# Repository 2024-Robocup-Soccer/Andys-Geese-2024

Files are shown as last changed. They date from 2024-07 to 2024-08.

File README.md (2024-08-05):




<h1 align="center" id="title">Robocup Soccer</h1>

<p id="description">A Lightweight Soccer Robot for Robocup Junior. Created by Matteo Cericola, John Qing, Sean Yien and Yuan Yoshimi. </p>

Documentation: https://andys-geese-2024.readthedocs.io/en/latest/

RoboCup is an international robotics tournament held around the world every year. More information can be found here: https://www.robocup.org/. The tournament we participated in this year was RoboCup Junior Lightweight.

<h2>Competition and Awards</h2>

2024 RCJ National Soccer Champion (Toronto)

2024 RCJ Regional Soccer Champion (Montreal)

2024 RCJ Regional Soccer Super Team Champion (Montreal)

<h2>3D Model Link</h2>

[https://a360.co/3x0yv2s](https://a360.co/3x0yv2s)

<h2>Project Pictures:</h2>

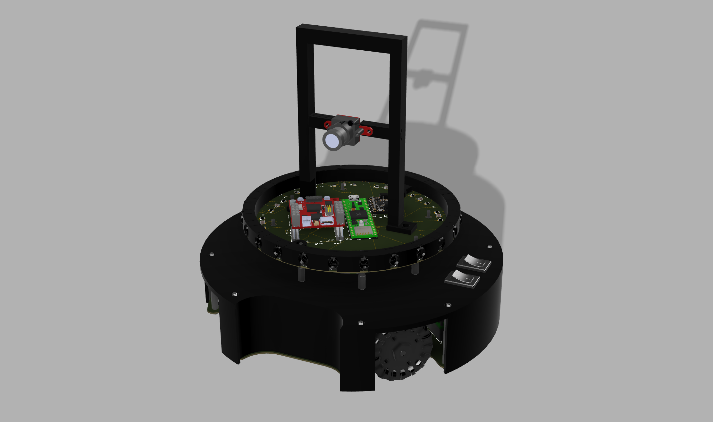
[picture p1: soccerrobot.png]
project-screenshot
 

project-screenshot 

<h2>💻 Built with</h2>

Technologies used in the project:

*   Fusion 360
*   VS Code (PlatformIO)
*   Prusa MK4 3D Printer
*   Teensy 4.1
*   OpenMv Camera
*   Adafruit BNO085 Compass
*   TSSP4038
*   GTF 50mm Omniwheels
*   GA25YN370 12V 1000RPM Motors
*   Pololu G2 High-Power Motor Driver 18v25
*   Photodiodes


CC BY-SA 4.0

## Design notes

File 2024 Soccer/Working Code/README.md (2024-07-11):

## Working Code
Here is where all the code being currently edited goes

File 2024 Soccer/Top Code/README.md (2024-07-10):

## These are the codes that are used in the top teensy.

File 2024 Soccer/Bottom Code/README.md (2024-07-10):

## These are the code for the bottom teensy.

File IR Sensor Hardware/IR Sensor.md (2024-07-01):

# Our IR Sensor
## Materials
- 12 TSSP4038 connected to a RC lowpass filter
- 12 TSSP4038 connected directly to a teensy 4.1

## Code
It uses a Taylor series to determine a function associated with the relationship between the intensity of the ball's signal and its distance from a given point.

## Shroud
After testing, we found that using a conical funnel directed toward the face of the sensors allowed for more reliable intensity values

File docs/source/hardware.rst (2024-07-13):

.. _hardware:

Hardware - Our Designs and Electronics
======================================

This section of the documentation will go over the specifics around our hardware, such as our electronic design process and 3D modelling.

We use Fusion 360 and Fusion 360 Electronics as our CAD software, and like before, associated files are available at our `GitHub <https://github.com/YuanYoshimi/RCJ-Soccer-Robot/>`_.

If you would like to download Fusion 360, the education edition is `free <https://www.autodesk.com/ca-en/products/fusion-360/education>`_. It contains all aspects of the paid license and is available to all students. Our files can be opened with the proper Fusion 360 Electronics and Fusion 360 software.

.. toctree::
    Infrared Sensors <irsensors>
    Color Sensors <colorsensors>
    3D Design <models>
    Design Process <dp>
    PCB Design <pcb>

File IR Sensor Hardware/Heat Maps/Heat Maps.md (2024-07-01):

These diagrams show the sensor output intensity when the ball is placed at any spot around it.

They were made by recording the intensity of each sensor when the ball was placed in seven 14 cm intervals infront of each sensor. The data was collected using the irCollection.ino file and the graph was made using gnuplot.

NOTE: THIS WAS THE OLD SENSOR WITH ONLY TSSP4038s CONNECTED TO A RC LOWPASS FILTER

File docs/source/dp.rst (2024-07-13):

.. _dp:

Design Process
==============

Our robot has undergone many iterations since the first protype design. However, we maintained a similar basic functionality all throughout. We identified the need for robot movement, orientation and ball detection as the required base functionality and therefore the highest priority to complete. As such, the first prototype iteration of the robot to explore these technologies included these three aspects of RCJ Soccer. The image to the right illustrates the prototype iteration of our robot, with the Modern Robotics IR Locator 3601, the Progressive Automations MultiMoto Arduino Shield with 4 H-Bridges2, a CMPS-123 (with BNO055 IC), and an Arduino Mega4 as the processor.

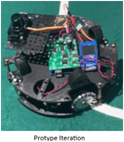
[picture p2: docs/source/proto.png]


The next iteration of the robot, the Regional Competition Iteration, we replaced multiple components and introduced the use of printed circuit boards to facilitate the transfer of data, as well as to provide a solid base and electrical pathways for the power supply. We also introduced the use of a 5V and a 3.3V step-down regulator in order to feed proper voltages to the new Teensy 4.1, BNO085, and ADG732 (referred to internally as the MuxBreakout). The image on the left shows all components mounted on both the top and bottom PCBs.

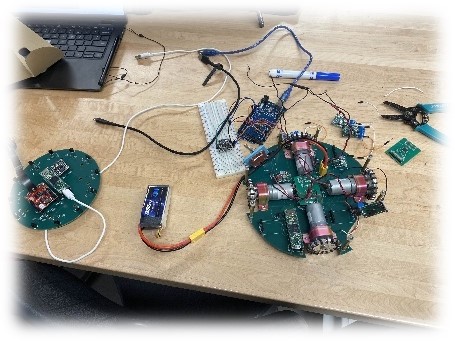
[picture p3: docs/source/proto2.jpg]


We stopped using the IR Locator 360 due to the unreliability as well as the halted production of the component. Instead, we opted for an IR Ring that employed the use of the TSSP4038, an IR receiver produced by Vishay. We also created a line sensor array with a colour sensor photodiode from Advanced Photonix, the 019-141-411-R SMD photodiode. The first iteration of the line sensor array used the OSRAM LS G6SP.02 SMD LED5 (see footnotes for reasons we no longer use this component). An OpenMV RT1062 was also mounted on the IR Ring and connected using extension cables to the mounting position on the handle of the robot.

The final iteration of the robot, the World Competition Iteration, involved all of the previous capabilities, with improvements to several systems and components. The bottom PCB had some fixes for mistakes on previous boards, different components, and filleted edges. Some problems with the MuxBreakout were also fixed, like a misplaced trace that was not caught by the DRC in Fusion 360 Electronics. All the printed circuit boards were switched to black, in order to minimize disruption to the IR sensors from reflected IR signatures.

The IR PCB was heavily modified. The sensor array was changed to 24 sensors, with 12 of them using a low-pass filter to convert the reading to an analog voltage based off distance, then read through the ADC (Analog to Digital Converter) on the Teensy 4.1 mounted on the IR Ring and the other 12 being directly read from the digital pins of the Teensy 4.1 by measuring the length of the pulses. This pulse measurement system will be explained further in the electronics section. The camera’s communication system was also switched over to SPI, to account for the difficulty in opening more than two serial ports on the Teensy 4.1. This will be discussed further in the technical sections.

Our game strategy was primitive in the Prototype Iteration. The only objective was for the robot to move forwards when the ball was directly in front. There was a BNO055 to do some adjustments, in case the robot ever stopped pointing forwards. The robot could not detect lines (see below) and would regularly violate the rules in search of the ball.

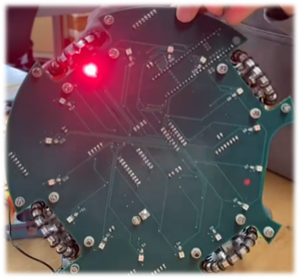
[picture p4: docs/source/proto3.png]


As you can see, the non functioning LEDs resulting in our color sensors being unusable.

The game strategy for the Regional Competition Iteration was slightly more complex, using a better BNO085 to adjust for angle, as well as a camera to aim for the goal. The new motor drivers allowed for more accurate motor speed control. However, some issues with the first LED generation caused the line sensors to malfunction, leading to an inability to control our robot’s movements within boundaries.

Finally, the game strategy for the Worlds Competition Iteration was much more complex. The angle correction featured a PID controller in order to prevent overturning and subsequently overturning again on the correction turn when the robot was wildly rocked out of control. We also identified five variables that we must always account for during the game. These were: ball angle (relative to the robot’s direction), ball distance (relative to the robot), robot direction, robot x (relative to the starting point), robot y (relative to the starting point). With these, we can perform PID again on the values to accurately move behind the ball and direct it to the goal with the help of the mounted camera. The values would work in tandem to the line sensors, which could provide an update to the x and y positions to account for any drift in the accelerometer.

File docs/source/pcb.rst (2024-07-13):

.. _pcb:

PCB Design
==========

Layer Stack
-----------

After doing much research, we decided to opt for a 4 layer PCB since it only requires a marginal increase in PCB production cost.

Our layer stack is illustrated here:
::
    Top -> Signal Layer
    Middle1 -> GND Plane
    Middle2 -> Pwr Plane (highest voltage takes priority, all other voltages are on a signal layer
    Bottom -> Signal Layer

You may notice that we have isolated power from our signal layers. Not only does this make it much easier to route the PCB (the different components who need power can just receive it from a via to the correct layer), it also helps prevent electromagnetic interference. Since pushing a voltage through a trace creates an electromagetic field around the moving electrons, by isolating the power with the signal, we have less chances of interference where the electromagnetic field created in the traces cause a current in the signal traces and renders our signals unreadable.

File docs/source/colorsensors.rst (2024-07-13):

.. _colorsensors:

Color Sensors
================

Principle
---------

The principle behind most color sensors (ours and commercial included) focuses on a basic physics concept known as color theory. As I'm not a real teacher, I am not fully qualified to teach this principle, but I can give a quick breakdown.

White light consists of three (primary) different colors: Red, Green, and Blue. We can make any color by mixing those. The reason we perceive that all objects have colors is because when white light (sunlight) is shone on the objects, their surface reflects a combination of Red, Green and Blue in order for those colors to mix and allow us to perceive a color. The surface in question, depending on their color, will absorb all light that doesn't reflect that color. Therefore, if we look at a green table under a white light, it absorbs all the other colors of light and reflects green light, which allows our eyes to perceive green. You may already know this but if you do not, here is an image that explains it better than me, courtesy of BYJU:

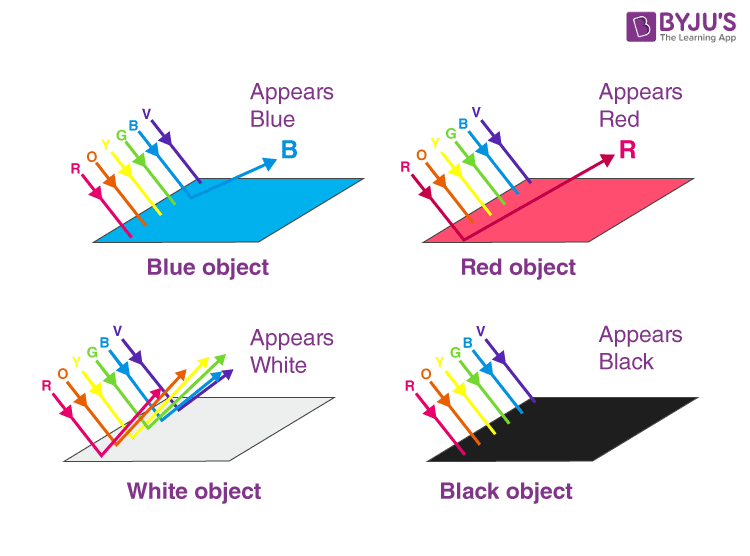
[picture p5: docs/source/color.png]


Thus, if a photodiode, filtered so that it only detects a certain color is pointed at the soccer table and provided with a color of light that will be absorbed by the green field and reflected by the white lines, is placed onto the bottom of the robot, it should in theory push a voltage if it is exposed to the white line.

In our case, the red LED will shine towards the field. If it hits the white line, it would reflect a red light to the photodiode. However if it hits the green field, the red light source does not have a component color of green to reflect. Therefore, the voltage reading should be lower.

This means that the photodiode can just push a voltage that can be read from an MCU.

The photodiode does not need to be connected to power, rather, it can be connected on one end to ground and one end to the analog pin. This is because it can push a voltage without needing a current, given a voltage can exist without current but not vice versa.

Again, arduino works remarkably well for this.

By running a simple analogIn(), the ADC on board can evaluate this analog value for the photodiode, and we can see a clear difference between the line and field.

Execution
---------

As always, principle works very differently from execution.

In this case, we first purchased a photodiode (THT and filtered for 940nm) and tested with a cheap THT (through hole technology) red LED. This actually (surprisingly) gave usable values.

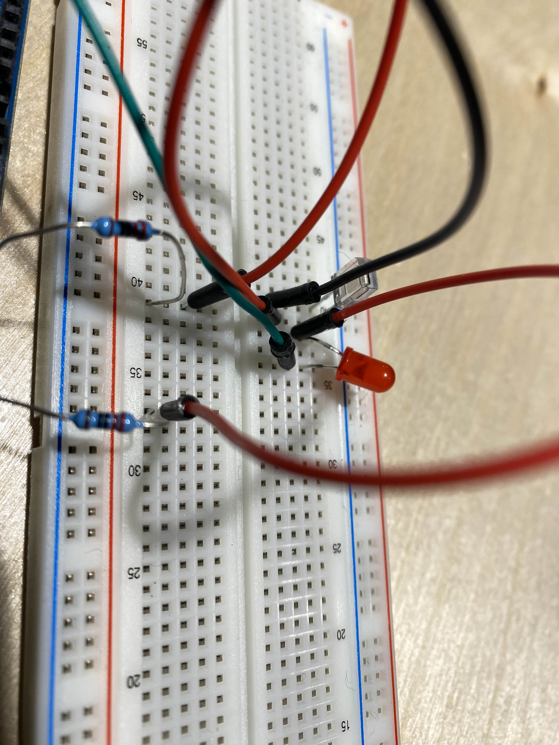
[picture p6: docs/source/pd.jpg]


We then adapted this design onto our bottom PCB.



However, since most MCUs don't have enough analog pins for an array of these, we had to make use of a multiplexer. Given our limited space, we opted for an SMD QFP package (search this up if you don't know what it is) 32 channel multiplexer.

We settled on the ADG732:

`Datasheet <https://www.analog.com/media/en/technical-documentation/data-sheets/adg726_732.pdf>`_

By placing this on a separate PCB and adding pin headers, we can make this modular and easy to replace in case of damage.

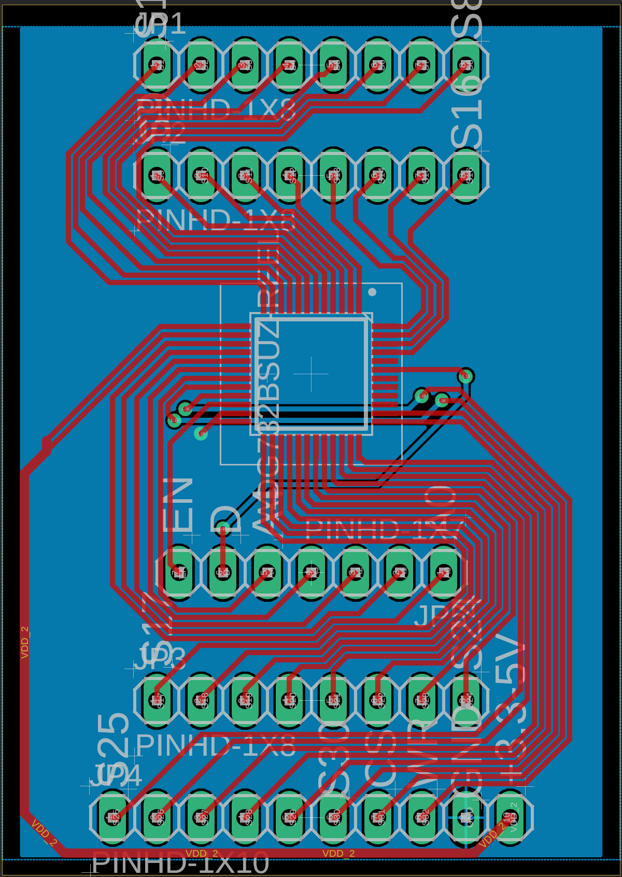
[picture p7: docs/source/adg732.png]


Now, by switching around the ports with code (through values given in the truth table), we can access each individual color sensor on the array.

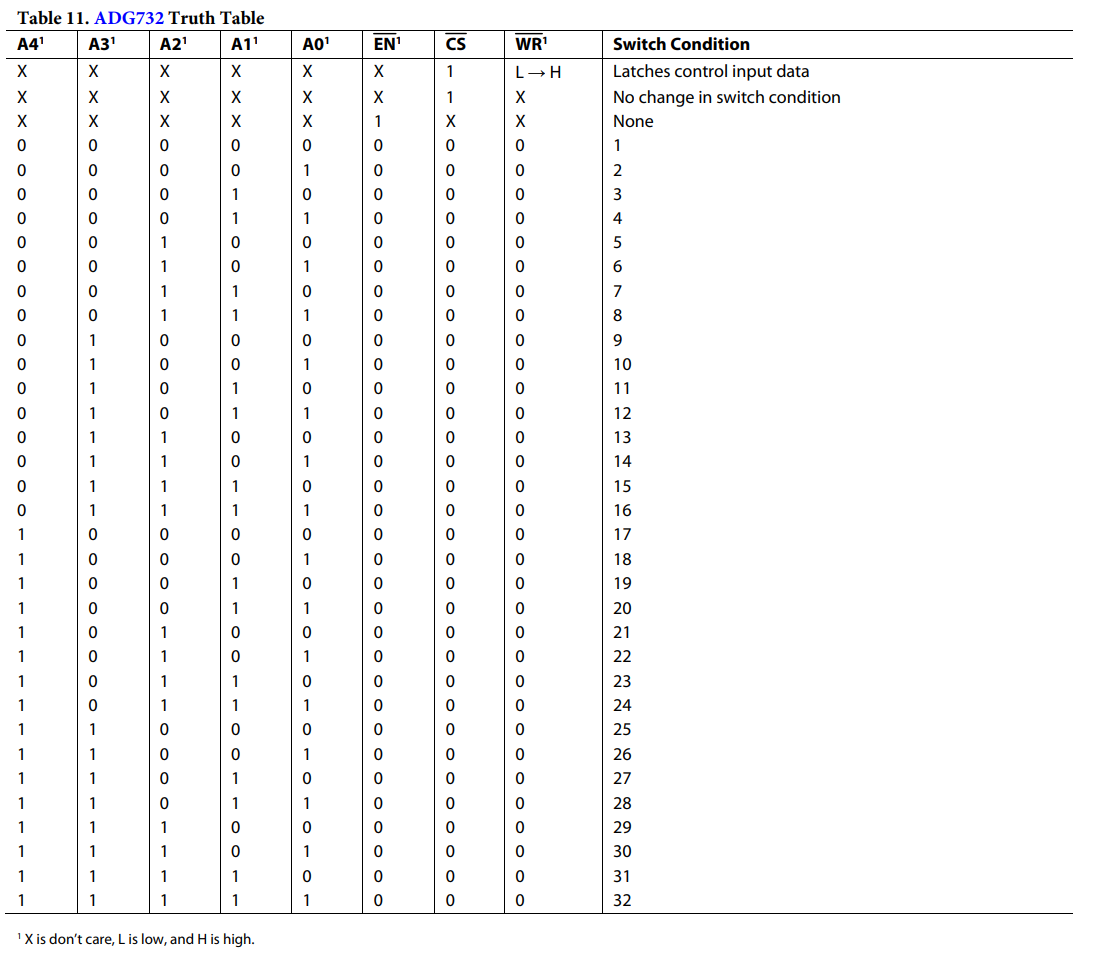
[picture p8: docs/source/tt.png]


The resulting PCB is shown below:

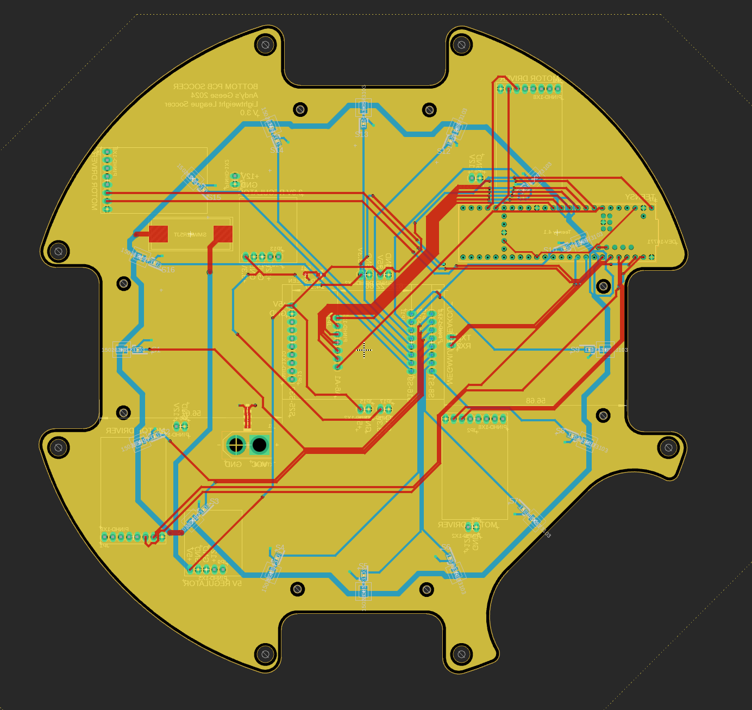
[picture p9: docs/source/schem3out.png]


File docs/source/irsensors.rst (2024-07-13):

.. _irsensors:

Infrared Sensors
================

The Infrared Sensors we used this year corresponded with the popular choices among past `competitions <https://github.com/robocup-junior/awesome-rcj-soccer?tab=readme-ov-file>`_.

We used the TSSP4038, which was a popular choice for IR detectors. We ordered ours from Mouser, but there are many other distributors who sell the TSSP4038.

`Datasheet <https://www.vishay.com/docs/82458/tssp40.pdf>`_

Initially, we had first experimented with the data output. Our oscilloscope indicated that the output was essentially a square wave. We did not understand the intensities at this point in time, so we placed a low-pass filter on it in order to read the square wave value as an analog input.

After playing around with the capacitor and resistor values as well as adding a pull up resistor, we were able to achieve a circuit with reasonable output on a breadboard. In later PCB designs, we used the same circuitry depicted in the schematic excerpt below:

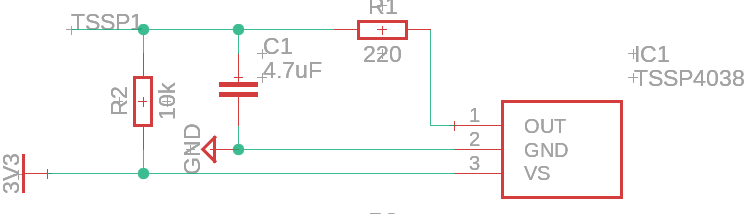
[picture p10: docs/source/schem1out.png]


However, as specified by datasheets and online, the output of the IR ball is quite a bit more complicated than what we saw with this simple circuit.

The ball outputs a stepped waveform of different groups of intensity. That means the ball will pulse at different intensities for a certain amount of times. This is depicted in the diagram below (Mode A since that is what is used in the international competition):

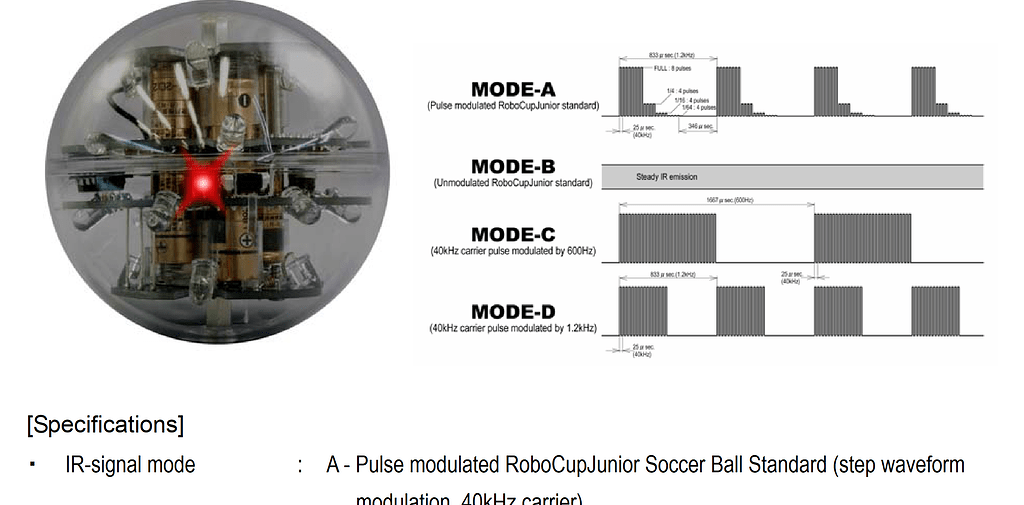
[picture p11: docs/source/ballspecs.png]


Thus, the dropping intensity near the end of the cycle means the further you are from the ball, the less you can see. Naturally, when light intensity drops below a certain threshold, the receivers can no longer distinguish between the ball's light and the ambient light. Therefore, the receiver no longer perceives the lower intensities the further away you move. This means that every time we move out of range of one intensity, the length of the square wave changes. And by sampling for this length, we can determine the distance from the ball, up to a resolution of approximately 5 different distances.

One might now ask, "how would I sample this distance"? Well, for one, pulseIn() on arduino works perfectly fine. What pulseIn() does is measure the length of a digital signal's state that it stays in. So if we connect both the grounds of the arduino (or other arduino avr board) and the receiver (this allows us to work with a common logic signal) and connect the output of the previously mentioned IR receiver, we can just directly pulseIn() to get the length of the pulse.

The code for this is really quite simple, an example is shown (assuming your IR output is connected to pin 1):
::
    //connections:
    //IR Receiver Out -> Digital Pin 1
    //IR Receiver GND -> Board Ground (This syncs their logic base level)
    //IR Receiver VCC -> Read datasheet for appropriate voltage.
    void setup()
    {
        pinMode(1, INPUT);
    }

    void loop()
    {
        int length = pulseIn(1, HIGH, 500); //note that we are reading HIGH, which means that we are looking for the length of the pulse when it is above logic low (logic ground)
    }

Alternatively, the option of using a low pass filter exists. This is because when we move out of an intensity's range, we no longer detect the pulses at that intensity. Therefore, the low pass filter will turn the wave into a lower analog signal, due to the decreased length of the wave.

Both work well, but the low pass filter method is easier if you have a slower MCU, since pulseIn() may not be accurate if your MCU clock speed is too low.

We adapted both low pass and pulseIn() for our PCB design, shown below (also found on our GitHub).

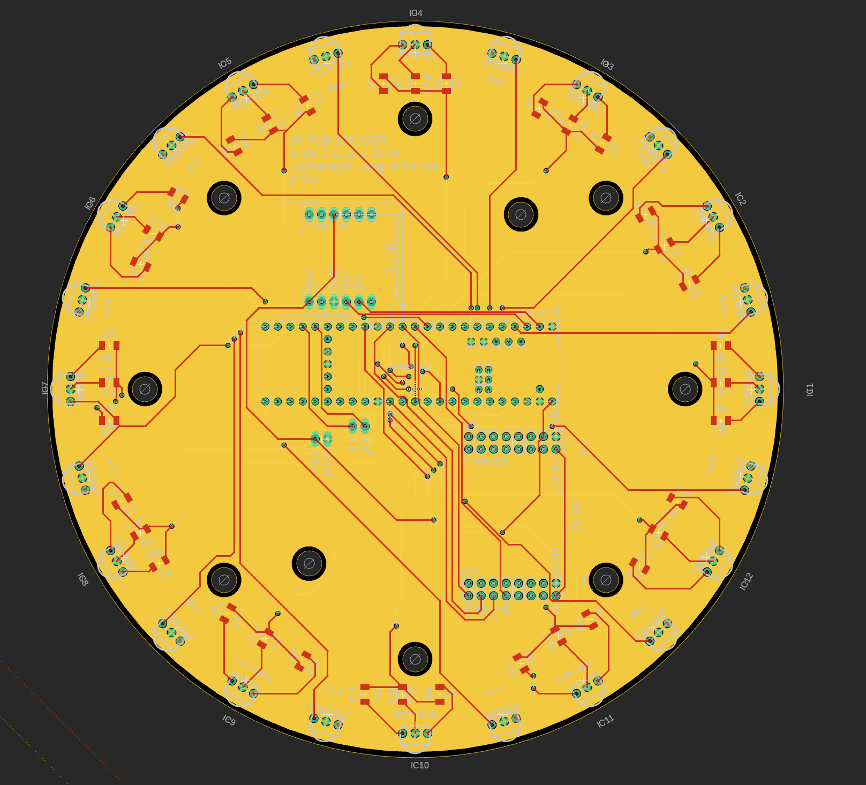
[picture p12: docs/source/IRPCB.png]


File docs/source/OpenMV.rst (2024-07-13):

.. _OpenMV:
OpenMV
======

Camera Detection
----------------

`GitHub <https://github.com/YuanYoshimi/RCJ-Soccer-Robot>`_

Camera detection is accomplished with an onboard library from OpenMV. Originally, we were faced with an issue with incompatibility. The pyb micropython library, which was originally intended for use with the stm32 microprocessor found on the OpenMV H7 was no longer usable with the i.MX RT1062 microprocessor on the OpenMV RT1062. Thus, we had to improvise our communication and detection systems.

**Detection**

The sensor object is still usable with the new microprocessor, so we were able to access the blob class. This class, combined with colorr thresholds, was able to identify the goals given their unique colors.
::

    thresholds = [
       (72, 90, -4, 36, 24, 48),
       (14, 33, -11, 10, -47, -12)
    ]

    blobs = img.find_blobs(thresholds, pixels_threshold=200, area_threshold=200)

This formulates the base of our detection capabilities. However, the camera can still see over the top of the field, so there may be some issues such as detection of blue and yellow shirts and non-game objects. Thus, we limit the detection area to under the halfway point and only identify the largest blob.
::
    if blobs:
        largest = blobs[0]
        for blobsss in blobs:
            if blobsss.area() > largest.area():
                largest = blobsss
    blob = largest
        if blob.cy() > (240/2)+20:
            # These values depend on the blob not being circular - otherwise they will be shaky.
            if blob.elongation() > 0.5:
                img.draw_edges(blob.min_corners(), color=(255, 0, 0))
                img.draw_line(blob.major_axis_line(), color=(0, 255, 0))
                img.draw_line(blob.minor_axis_line(), color=(0, 0, 255))
            # These values are stable all the time.
            img.draw_rectangle(blob.rect())
            img.draw_cross(blob.cx(), blob.cy())

            if blob.cx() < (320/2)-bufferVal:
                print("Left: " + str(int(maptrans(blob.cx(), 0, 320, 0, 250))))
                print(int(maptrans(blob.cx(), 0, 320, 0, 250)))
                pwm.duty_ns(int(maptrans(blob.cx(), 0, 320, 0, 250))*1000)
            elif blob.cx() > (320/2)+bufferVal:
                print("Right: " + str(int(maptrans(blob.cx(), 0, 320, 0, 250))))
                pwm.duty_ns(int(maptrans(blob.cx(), 0, 320, 0, 250))*1000)
            else:
                print("Center: " + str(int(maptrans(blob.cx(), 0, 320, 0, 250))))
                pwm.duty_ns(int(maptrans(blob.cx(), 0, 320, 0, 250))*1000)

            if blob.area() > 8000:

                print("Near")

            # Note - the blob rotation is unique to 0-180 only.
            img.draw_keypoints(
                [(blob.cx(), blob.cy(), int(math.degrees(blob.rotation())))], size=20
            )
        #print(clock.fps())

    else:
        pwm.duty_ns(500000)
    print(pwm.duty_ns())

**Communication**

You will notice that part of the previously created code also includes the communication protocol. Although originally we were planning on using SPI for communication, the difficulty of slaving the OpenMV camera for data transfer so that both SCK pins would not attempt to simultaneously drive the clock signal resulted in us attempting a different approach:
::
    from machine import PWM
    from machine import Pin
    
    p = Pin("P3", Pin.OUT)

    pwm = PWM(p, 1000)

This sets up a PWM object given by the OpenMV library for use with pins on the RT1062. By modifying the duty cycle %, we can send a pulse with a different width. We decided to use this width, measuring in microseconds, to transfer our data.

We began by mapping (see API reference :py:func:`maptrans`) the x pixel value that we get a value from 0-250 that we send in the PWM signal. When there is no goal detected, we will send a PWM signal of 500.
::
    def maptrans(num, inMin, inMax, outMin, outMax):
        return outMin + (float(num - inMin) / float(inMax - inMin) * (outMax - outMin))

Then, we can adjust the width of the pulse (duty cycle %) with `pwm.duty_ns <https://docs.openmv.io/library/machine.PWM.html>`_

This way, when read from the Teensy, we can just use pulseIn().
::
    int val = pulseIn(10, HIGH, 1000);
    if (val>0){
        Serial.println(val);
    }

A value of 1000 for the timeout is required since the width of the pulses are hundreds of microseconds, so we must have 1000 µs as a timeout time in order to catch the entire pwm signal rather than parts of a pwm signal.

The resulting square wave is visible on an oscilloscope. Thus we can be assured that the signal is indeed being produced when degbugging.

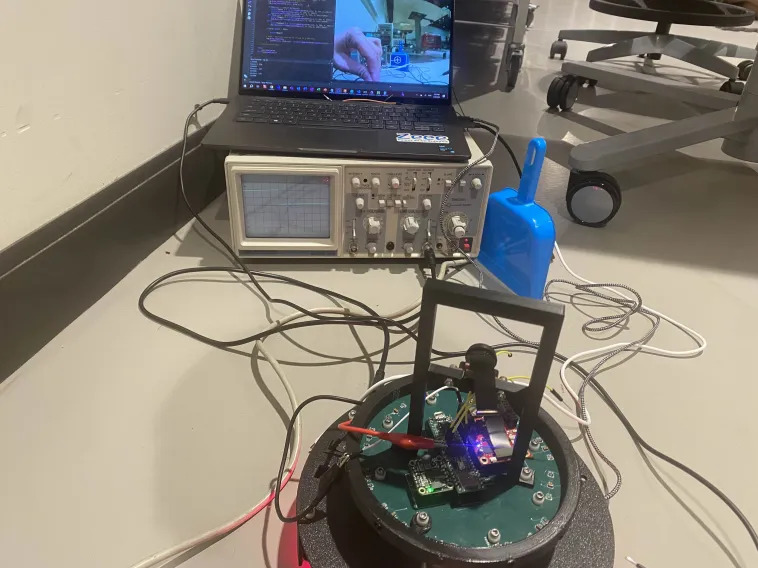
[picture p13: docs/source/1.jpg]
setup picture


API Reference
-------------

.. py:function:: maptrans(num, inMin, inMax, outMin, outMax)

    Translate/map a value from one range to another range.

    :param num: The number to be translated.
    :param inMin: The minimum of the input range.
    :param inMax: The maximum of the input range.
    :param outMin: The minimum of the output range.
    :param outMax: The maximum of the output range.
    :type num: int, float
    :type inMin: int, float
    :type inMax: int, float
    :type outMin: int, float
    :type outMax: int, float
    :return: The value from the original range mapped to the equivalent value of the new range.
    :rtype: int

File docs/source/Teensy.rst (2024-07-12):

.. _Teensy:

Teensy
======

motorControlV3
--------------

.. cpp:class:: motorControlV3::Motor

    Motor class, handles all of our motor controls. Accessed by the bottom file.

    .. cpp:function:: void motorControlV3::Motor::initMotors(void)

        Initializes the pins. Pins are hard-locked to 3, 1, 5, 37 for the direction pins and 2, 0, 4, 36 for the pwm pins for the `Pololu G2 24v21 Motor Drivers <https://www.pololu.com/product/2995>`_.

    .. cpp:function:: void motorControlV3::Motor::setMotor(int motor, int dir, int pwm)

        Sets one motor direction and speed.

            - int motor: Motor number that should have its speed and direction set. Not needed when calling `:cpp:class:motorControlV3::Motor::moveRobot`.
            - int dir: direction value (0 or 1)
            - int pwm: pwm value to send to power motors at a certain speed (0-255)

    .. cpp:function:: int motorControlV3::Motor::movementSineFunction(int motor, float ballAngleDegrees, boolean isCounter, int amplitude)

        Uses a sine function associated with each motor assembly to move in a direction from the according point in the sine wave given the ball direction.

        Returns an integer value for the pwm motor value for the motor given in the parameters.

            - int motor: Motor number that we are calculating the appropriate value for.
            - float ballAngleDegrees: Degrees of ball angle given in the IR code as a floating point number.
            - boolean isCounter: True if motor is backwards, else false.
            - int amplitude: Amplitude of the sine wave, also the distance to the ball that we want to stay away when navigating to the perpendicular.

    .. cpp:function:: void motorControlV3::Motor::moveRobot(int speed1, int speed2, int speed3, int speed4)

        Move robot with the speeds given for motors 1-4.

            - int speed1: Speed of motor 1. (Can be -255 to 255)
            - int speed2: Speed of motor 2. (Can be -255 to 255)
            - int speed3: Speed of motor 3. (Can be -255 to 255)
            - int speed4: Speed of motor 4. (Can be -255 to 255)

colorSensorV2
-------------
.. cpp:class:: colorSensorV2::ColorSensor

    ColorSensor class, handles all the input from our color sensors. There are 16 color sensors: 16 LEDs and 16 940nm photodiodes. All photodiodes output an analog value which is read by the ADC of our bottom Teensy.

    .. cpp:function:: int colorSensorV2::ColorSensor::readSensor(int sensor)

        Read the sensor specified and returns an arbitrary int value for the detected amount of red light that is used in comparisons with other values.

            - int sensor: Takes the sensor pin number. Refer to schematics for sensor numbers.

    .. cpp:function:: void colorSensorV2::ColorSensor::colourSensorInit(void)

        Initializes color sensors. Takes no parameters.

Compass
-------

.. cpp:class:: Compass::Compass

    Compass class, uses Adafruit.h as a dependency for access to the BNO085 compass output.

    .. cpp:function:: void Compass::Compass::init(void)

        Initialize the compass by beginning Serial connection to the BNO085.

            Does not print anything and just opens the connection.

    .. cpp:function:: void Compass::Compass::initPrint(void)

        Initialize the compass by beginning Serial connection to the BNO085.

            Prints a confirmation message and opens the connection.

    .. cpp:function:: void Compass::Compass::resetCheck(void)

            Checks if BNO085 has been reset. Sets the desired output again.

                Does not print a confirmation message and just performs the check and set.

    .. cpp:function:: void Compass::Compass::resetCheckPrint(void)

            Checks if BNO085 has been reset. Sets the desired output again.

                Prints a confirmation message and performs the check and set.

    .. cpp:function:: float Compass::Compass::getBotAngle(void)

            Gets the current bot angle based off the BNO085

                Returns a floating point value of the angle scale value from -1.00 to 1.00 where 0 is the direction it initializes in.

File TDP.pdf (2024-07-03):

Team Design Paper: Andy’s Geese

John Qing, Matteo Cericola, Yuan Yoshimi, Sean Yien, Josh Wang (retired) Dr. Benjamin Lawrence, Ms. Meera Balendran St. Andrew’s College
15800 Yonge Street, Aurora, ON, CA

Abstract
This report serves as the documentation and description for team Andy’s Geese in preparation for RoboCup Junior 2024. In this paper, we discuss aspects of our team and the composition of our robots, as well as details of learning. We will begin by describing our team, then identifying the composition of the technology in our robot, and finally discussing some future steps as well as what we had learned.

Introduction
Team Background
Team Photo

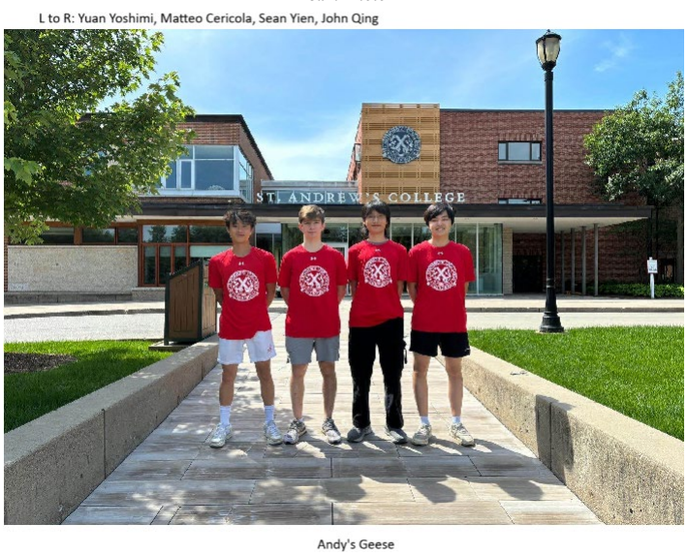
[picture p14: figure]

Team Foundation
Andy’s Geese was first formed in February 2024 in preparation for RoboCup 2024. We were planning on competing in our regional tournaments in April of 2024 and possibly in the world tournament in July of 2024. Although our team formed very
recently, our founding members were part of the DYMJ-Alpha (picture to the right) who competed in Bordeaux in 2023. Other members also brought a wealth of experience, with one hailing from the Canadian Rescue Line team that participated in the Bordeaux competition, and the other with a wealth of experience in embedded systems programming and a mastery in C++.

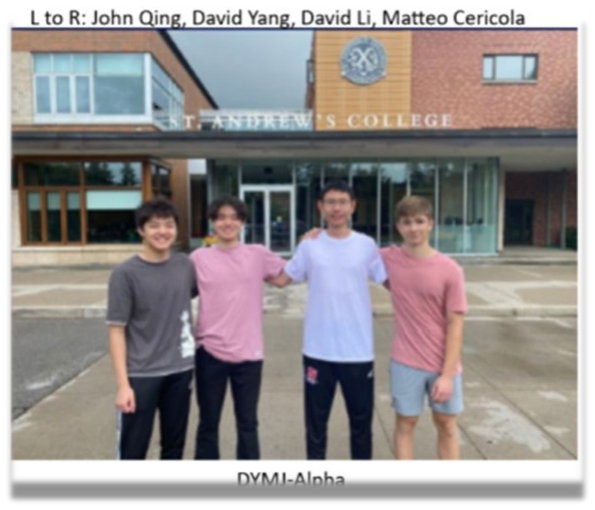
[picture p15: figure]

Team Composition
Our team consists of four people, with one former member who retired from active participation in RoboCup Junior.
Active Members:
John Qing – Engineer, Programmer, Electrical Design, Design Paper Writer, Data Analysis
Matteo Cericola – Programmer, Engineer, Data Analysis
Yuan Yoshimi – Engineer, Programmer, Data Analysis, 3D Designer, Mechanical Deisnger
Sean Yien – Electrical Design, Engineer, Poster Design
Former Members:
Josh Wang – Programmer, Poster Design

Team Accomplishments and Qualification Our team achieved both first place in the regular competition as well as the Superteam competition in the RoboCup Junior Regional Tournament in Montreal, Quebec. We faced many competent teams from Eastern Canada. Less than a week later, our team also achieved first place in the RoboCup Junior National Tournament in Aurora, Ontario (pictured to the left).
After receiving word of our qualification to the RCJ World Championships in Eindhoven, we began work on our final iteration of our robot we intend to bring to the Netherlands.

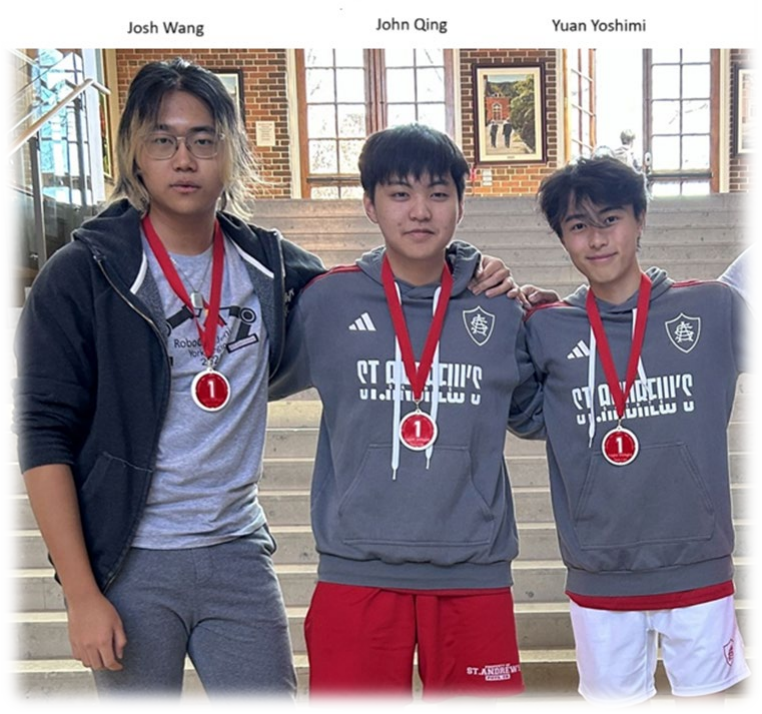
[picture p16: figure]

Robot Development
Design Overview
Our robot has undergone many iterations since the first protype design. However, we maintained a similar basic functionality all throughout. We identified the
need for robot movement, orientation and ball detection as the required base
functionality and therefore the highest priority to complete. As such, the
first prototype iteration of the robot to explore these technologies included these three aspects of RCJ Soccer. The image to the right illustrates the prototype iteration of our robot, with the Modern Robotics IR Locator 360¹ ,
the Progressive Automations MultiMoto Arduino Shield with 4 H-Bridges² ,

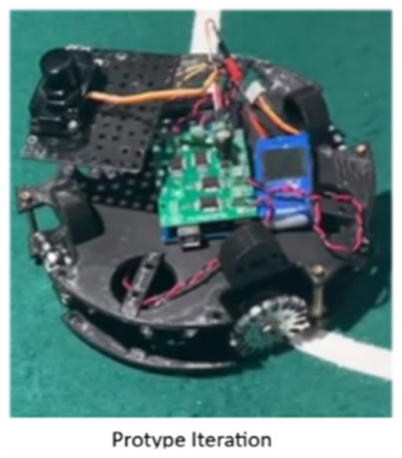
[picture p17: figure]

a CMPS-12³ (with BNO055 IC), and an Arduino Mega⁴ as the processor (see footnotes for reasons we no longer use these).
The next iteration of the robot, the Regional Competition Iteration, we replaced multiple components and introduced the use of printed circuit boards to facilitate the transfer of data, as well as to provide a solid base and electrical pathways for the power supply. We also introduced the use of a 5V and a 3.3V step-down regulator in order to feed proper voltages to the new Teensy 4.1, BNO085, and ADG732 (referred to internally as the MuxBreakout). The image on the left shows all components mounted on both the top and bottom PCBs.

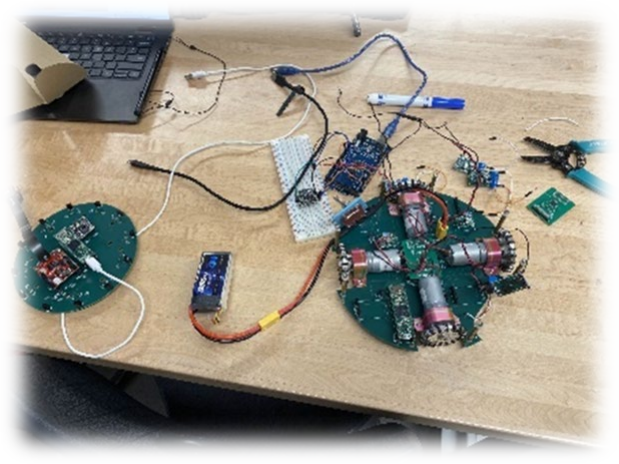
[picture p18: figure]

We stopped using the IR Locator 360 due to the unreliability as well as the halted production of the component. Instead, we opted for an IR
Ring that employed the use of the TSSP4038, an IR
receiver produced by Vishay. We also created a line sensor
array with a colour sensor photodiode from Advanced Photonix, the 019-141-411-R SMD photodiode. The first iteration of the line sensor array used the OSRAM LS G6SP.02 SMD LED⁵ (see footnotes for reasons we no
longer use this component). An OpenMV RT1062 was
also mounted on the IR Ring and connected using

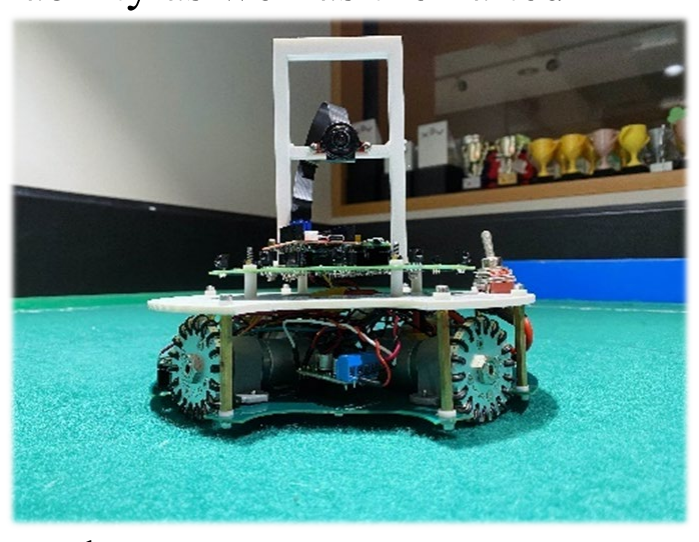
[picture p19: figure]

extension cables to the mounting position on the handle of the robot.
The final iteration of the robot, the World Competition Iteration, involved all of the previous capabilities, with improvements to several systems and components. The bottom PCB had some fixes for mistakes on previous boards, different components, and filleted

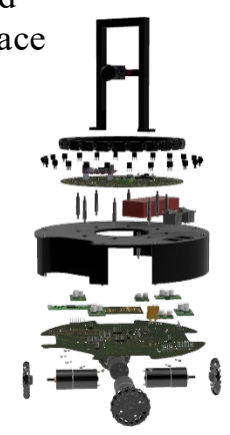
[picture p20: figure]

edges. Some problems with the MuxBreakout were also fixed, like a misplaced trace
that was not caught by the DRC in Fusion 360 Electronics. All the printed circuit
boards were switched to black, in order to minimize disruption to the IR sensors from reflected IR signatures.
The IR PCB was heavily modified. The sensor array was changed to 24 sensors, with 12 of them using a low-pass filter to convert the reading to an analog voltage based off distance, then read through the ADC (Analog to Digital Converter) on the Teensy 4.1 mounted on the IR Ring and the other 12 being
directly read from the digital pins of the Teensy 4.1 by measuring the length of
the pulses. This pulse measurement system will be explained further in the
electronics section. The camera’s communication system was also switched over to SPI, to account for the difficulty in opening more than two serial ports on the Teensy 4.1. This will be discussed further in the technical sections.

Our game strategy was primitive in the Prototype Iteration. The only objective was for the robot to move forwards when the ball was directly in front. There was a BNO055 to do some adjustments, in case the robot ever stopped pointing forwards. The robot could not detect lines and would regularly violate the rules in search of the ball.
The game strategy for the Regional Competition Iteration was
slightly more complex, using a better BNO085 to adjust for angle, as well
as a camera to aim for the goal. The new motor drivers allowed for more accurate motor speed control. However, some issues with the first LED
generation caused the line sensors to malfunction, leading to an inability to
control our robot’s movements within boundaries.

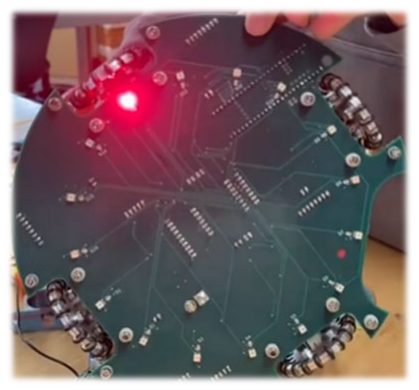
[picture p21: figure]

Finally, the game strategy for the Worlds Competition Iteration was much more complex. The angle correction featured a PID controller in order to prevent overturning and subsequently overturning again on the correction turn when the robot was wildly rocked out of control. We also identified five variables that we must always account for during the game. These were: ball angle (relative to the robot’s direction), ball distance (relative to the robot), robot direction, robot x (relative to the starting point), robot y (relative to the starting point). With these, we can perform PID again on the values to accurately move behind the ball and direct it to the goal with the help of the mounted camera. The values would work in tandem to the line sensors, which could provide an update to the x and y positions to account for any drift in the accelerometer.

Design Specifics
In this section, the details relating to the choices for the mechanical design, as well as trials and failures are documented. Our GitHub repository⁶ (linked in the footnotes) contains all the designs, for public use and for all future teams.
Mechanical Design
The mechanical aspect of the robot was designed with fusion 360 allowing us to model our robot. The 3D printed pieces consist of a main
cover/chassis, handle, motor mount, IR shroud and the motor
standoffs.
Different mechanical parts of the robot experience varying amounts and types of stress, as well as varying material requirements. We have experimented with different types of filament for the 3D prints such as PLA, PETG and a carbon fiber filament. Initially we planned on using the carbon
fiber filament as it has a exceptional strength and
performance, but we found out that the prints were poorly

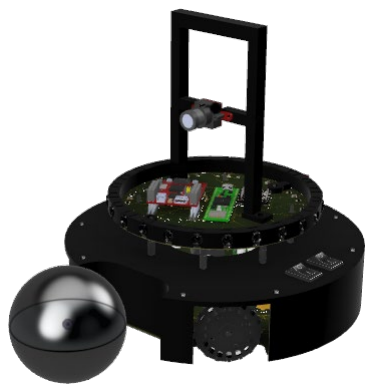
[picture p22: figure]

done and some were unusable. After testing, all our 3d printed pieces are using the PLA filament because of its reliability and the printer working well with it.

Electrical Design
The diagram picture below depicts all the data transferred by all the components and labelled by the communications protocol, as well as the flow of power from the battery. All electrical designs were done on Fusion 360 Electronics, since it provides good integration for the final 3D model.

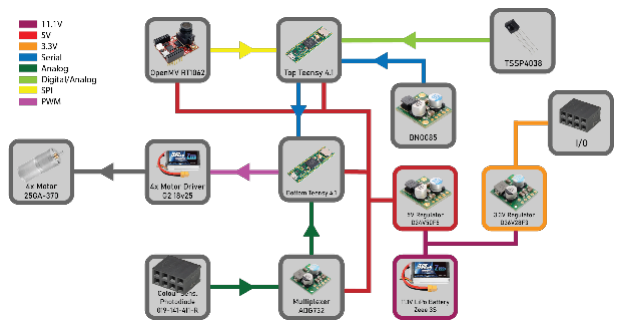
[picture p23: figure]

The schematic for the bottom PCB is shown below. Since we did not go through the trouble of creating custom fusion libraries for the components that we created, like the MuxBreakout board, we ended up just using header pins and accurately measuring the I/O pins of all our own components and the ones we bought commercially.

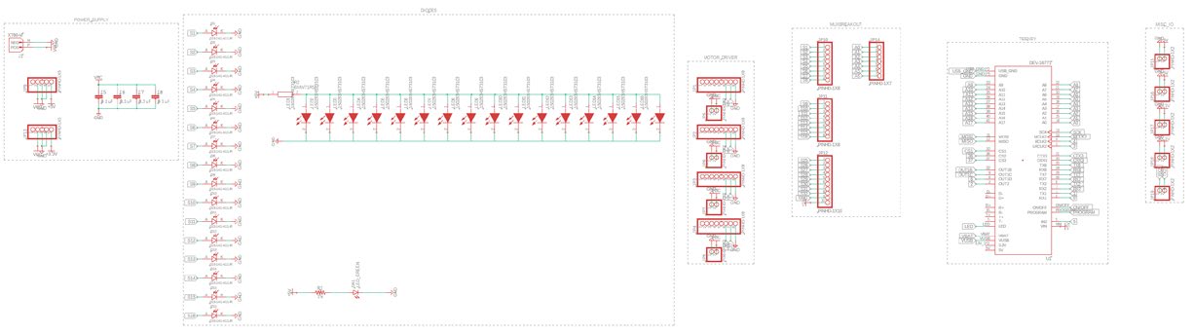
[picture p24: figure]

The layer stack for all of our PCBs is shown to the left. We opted for a 4-layer PCB since it had the same production costs as the 2 layer PCB, with the added benefit of a ground plane and a 12V plane, following PCB design conventions. The layer stack we opted for was signal-ground-12v-signal. This allowed for easy access to the ground planes with vias as well as easy access to the 12V source without needing to run them as traces in the signal plane, thereby reducing EM interference between traces.
In the following image, the schematic and the PCB design for the IR Ring is shown. The ANALOG_IC group contains the low-pass filtered IR receivers. The circuit contains a low pass filter (resistor and capacitor) as well as a 10k pull-up resistor.

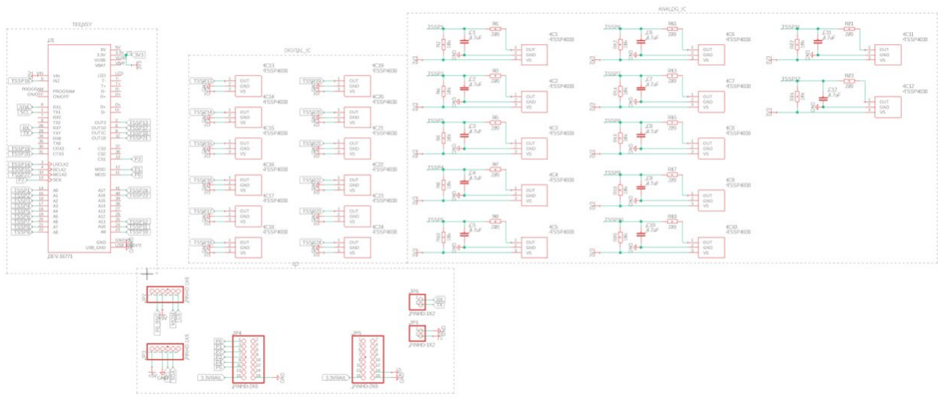
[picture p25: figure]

During testing, we discovered that by limiting the field of view with a shroud, we could more effectively isolate the direction of the incoming IR signature. In the following heatmaps, a shroud was applied to one and not in the other. The directional readings were much better after the shroud was applied. Therefore, with this setup, we can accurately determine the direction of the ball down to approximately 7.5-15 degrees and potentially even more accurate as we get closer.


The principle behind the low-pass filters and measuring the length of the pulses lies behind the trapezoid-wave with steps of intensity of the IR LEDs. As seen in the image below (taken from the RCJ forums)⁷ Mode A, which contains the trapezoid-wave is used. By capturing where signal strength drops off, we can assign that specific length of the square wave to a predetermined location. This can then be read using pulseIn() or a timer-checker loop and a rough distance can be caalculated. In our experience, however, there does not exist enough steps of the wave for certainty in terms of distance, and a low-pass filter to normalize the signal provides better long-distance detection. We decided to use both in order to achieve the maximum resolution at all distances.


Communication is achieved with both SPI and UART. Due to an issue on the Teensy 4.1 where opening more than two Serial ports would interfere with the operation of the
robot, we decided to use SPI for certain aspects of the Robot. UART at the maximum
speed of 20,000,000 Baud can operate at the equivalent data transfer rate of 20 mhz.

This is sufficiently fast for us to transfer instructions for our motors from our top Teensy and receive information from the bottom Teensy to compute.
The MuxBreakout, the custom designed component with the ADG732 multiplexer IC includes a mechanism to keep it permanently on. The IC contains WR (Write),
EN (Enable) and CS (Chip Select) pins. These are all to be set to logic low
according to the truth table from the datasheet provided by the manufacturer
while the IC is operating. Therefore, in our component, we connected all of
them to the same pin that is to be set to logic low. While these traces cannot be
seen in the PCB pictured to the right, they consist of three simple traces
designed to keep this IC on at all times, given that we do not need the extra functionality.
We custom mounted most of the SMT components on our PCBs. To do this, we acquired a T962A reflow oven for amateur use. By ordering stencils from
the factory, we could use a blank RFID card from the RFID kit
provided in Arduino kits and squeegee the solder paste. Since
the solder paste was Lead based and was composed of a mixture of 63% Tin and 37% Lead, we worked in our school’s advanced chemistry lab, where we had access to fume hoods for proper
fume control when using the oven and large quantities of 99.9%
IPA (isopropanol alcohol), the manufacturer prescribed method


of cleaning solder paste from stencils. We placed all components with tweezers and by hand. In order to conform to MSL (Moisture Sensitivity Level)
requirements, we baked all components which were exposed to room
humidity in accordance with the temperature and time described in J-STD-
033. Since we were working with MSL 3 components, we baked all of our components at 125℃ for 9 hours. Since the thickness was below 1.4mm. We used an oven with precise temperature control and watch glasses to contain
the components to be baked.
Software
Behind our robot's program is the consistent development of five values: robot angle, robot x, robot y, ball angle, and ball distance. These values allow the bot to understand the field and determine the best holistic action. In previous years, we had made concrete decisions based on one data collection method. An example would be when our robot detected it was above a line; it would automatically move inward to avoid moving out of bounds. Instead, this year, we have made an algorithm that simply understands it is on the line and restricts movement accordingly. To calculate these values, we are using the Adafruit BNO085 to calculate the robot angle, x, and y, and the IR sensor to find the ball angle and distance from our robot.
These five values are then sent from our top microcontroller to the bottom microcontroller using UART in a six-cycle process. First, 255 is sent to mark the beginning of the cycle, followed by five bytes, each representing each value mapped to a value between 0 and
250. Once received, these values are remapped to their original values to be used to determine the robot’s next move, which is determined by a priority list. As to move, our robot needs to understand how it is oriented, our robot adjusts rotation before anything. After this, it takes into consideration the line and restricts movement past it when it is detected. Then the robot moves behind the ball, and only when it is aligned correctly it moves forward to try and score. This priority list generates a desired angle, x, and y position.
From that, three PID controllers, one for calculating y movement, x movement, and rotation, are fed this desired positioning. These controllers find the displacement required to get to the desired position, the derivative of displacement, and the integral of displacement. The output of these functions are associated motor values that add to make up the total motor value. Each TSSP4038 is associated with a Taylor series function to find the direction and distance of the IR ball. This association is created by measuring the output intensity of each sensor at one-cm increments for two meters. These values are then graphed, and the corresponding Taylor series function is created to fit the curve. Initially, we used an inverse square fit, but as the inverse square law does not fully explain the output, since the silicone also plays a significant role in the shape of the curve, an nth-degree polynomial generated from the Taylor series considers these other factors.
Reflection
We also explored other aspects of improvement for our robot, namely
with the TSSP4P38. This sensor was a derivative of the TSSP4038, but with an AGC that would try and suppress the IR signature. Once it was suppressed, the return of the sensor was the time it takes to suppress the signal as a pwm signal. However, the engineers at Vishay pointed out that the suppression time was
approximately 130ms in some cases, which is just too slow for a fast-paced
soccer game.
We also noted the importance of being able to detect if we are directly in front of the ball, and noted that in a future design, we can open up a hole in the front kicking section of the robot and allow an IR receiver to check if the ball is in the right position.
Finally, we entertained the possibility of a kicker and a dribbler mechanism. While both in theory would be easy to add on even with less than two weeks until the competition since they can be externally attached modules with wires running to them, we decided against implementing them. This is because of the efficiency of kinetic energy transfer when hitting the ball, and the other two would make little difference unless we are working with special methods of hiding and lobbing the ball. Given our time constraints, we disregarded these and focused on our existing parts and getting them ready for the competition.
One very important lesson we learned was the importance of starting early. Since we started about four to five months before the Eindhoven competition, we were faced with many issues such as procuring motors. Most motors that are commonly used in the robocop competitions like Maxon and Faulhaber motors have a lead time of up to a few months. This would massively surpass our timeframe. Therefore, we opted for fast motors from amazon that are low quality but large in quantity. We could speedily replace all of our motors upon failure. But this does not at all mean that starting early would not be hugely beneficial for our robot quality.
Additionally, after conferring with other teams, we concluded that RoboCup innovation is being stifled by the lack of a better trapezoid waveform from the ball. As seconded by the engineers at Vishay, “you probably do not have enough steps and your timing is too short”.⁸ Therefore, more varying intensities could be beneficial, as shown in the diagram below provided in the email from the engineers at Vishay. We could read a pseudo-analog value from our sensors by measuring the width of the pulse as a result, increasing our resolution.


Footnotes and References
1 https://modernroboticsinc.com/product/ir-locator-360/ – No longer produced
2 https://www.progressiveautomations.ca/products/lc-82 – No longer used due to low amperage tolerance and tendency to short circuit from minor mis-operation
3 https://ca.robotshop.com/products/tilt-compensated-magnetic-compass-cmps12 – No longer used in favor of BNO085
4 https://store.arduino.cc/products/arduino-mega-2560-rev3 – No longer used in favor of Teensy 4.1’s Arm Cortex M7 core.
5 https://www.mouser.ca/ProductDetail/ams-OSRAM/LS-G6SP.02-6D5E-67-G3R3-140-R18-Z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 (https://www.mouser.ca/ProductDetail/ams-OSRAM/LS-G6SP.02-6D5E-67-G3R3-140-R18-Z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) – No longer used due to SMD mounting difficulties as well as common short circuits due to the pad positioning
6 GitHub repository: https://github.com/YuanYoshimi/RCJ-Soccer-Robot
7 https://junior.forum.robocup.org/t/ir-ball-modulation-change-proposal/3672

8
Dr. Sebastian Schaefer, Application Engineer, IR-Receiver & IRDA


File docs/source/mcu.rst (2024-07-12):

.. _mcu:
MCUs -  All About Our Code
==========================
This section of the documentation will go over everything code related. An explanation of all the communication protocols, as well as the API references for our custom libraries. Again, you may find the associated code at our `GitHub <https://github.com/YuanYoshimi/RCJ-Soccer-Robot>`_ in the appropriate namespaces.

.. toctree::
   Teensy
   OpenMV

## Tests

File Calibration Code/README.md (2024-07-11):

## Calibration Code
Code within this folder is used to get sample data from which the actual code compares with the data it collects to work

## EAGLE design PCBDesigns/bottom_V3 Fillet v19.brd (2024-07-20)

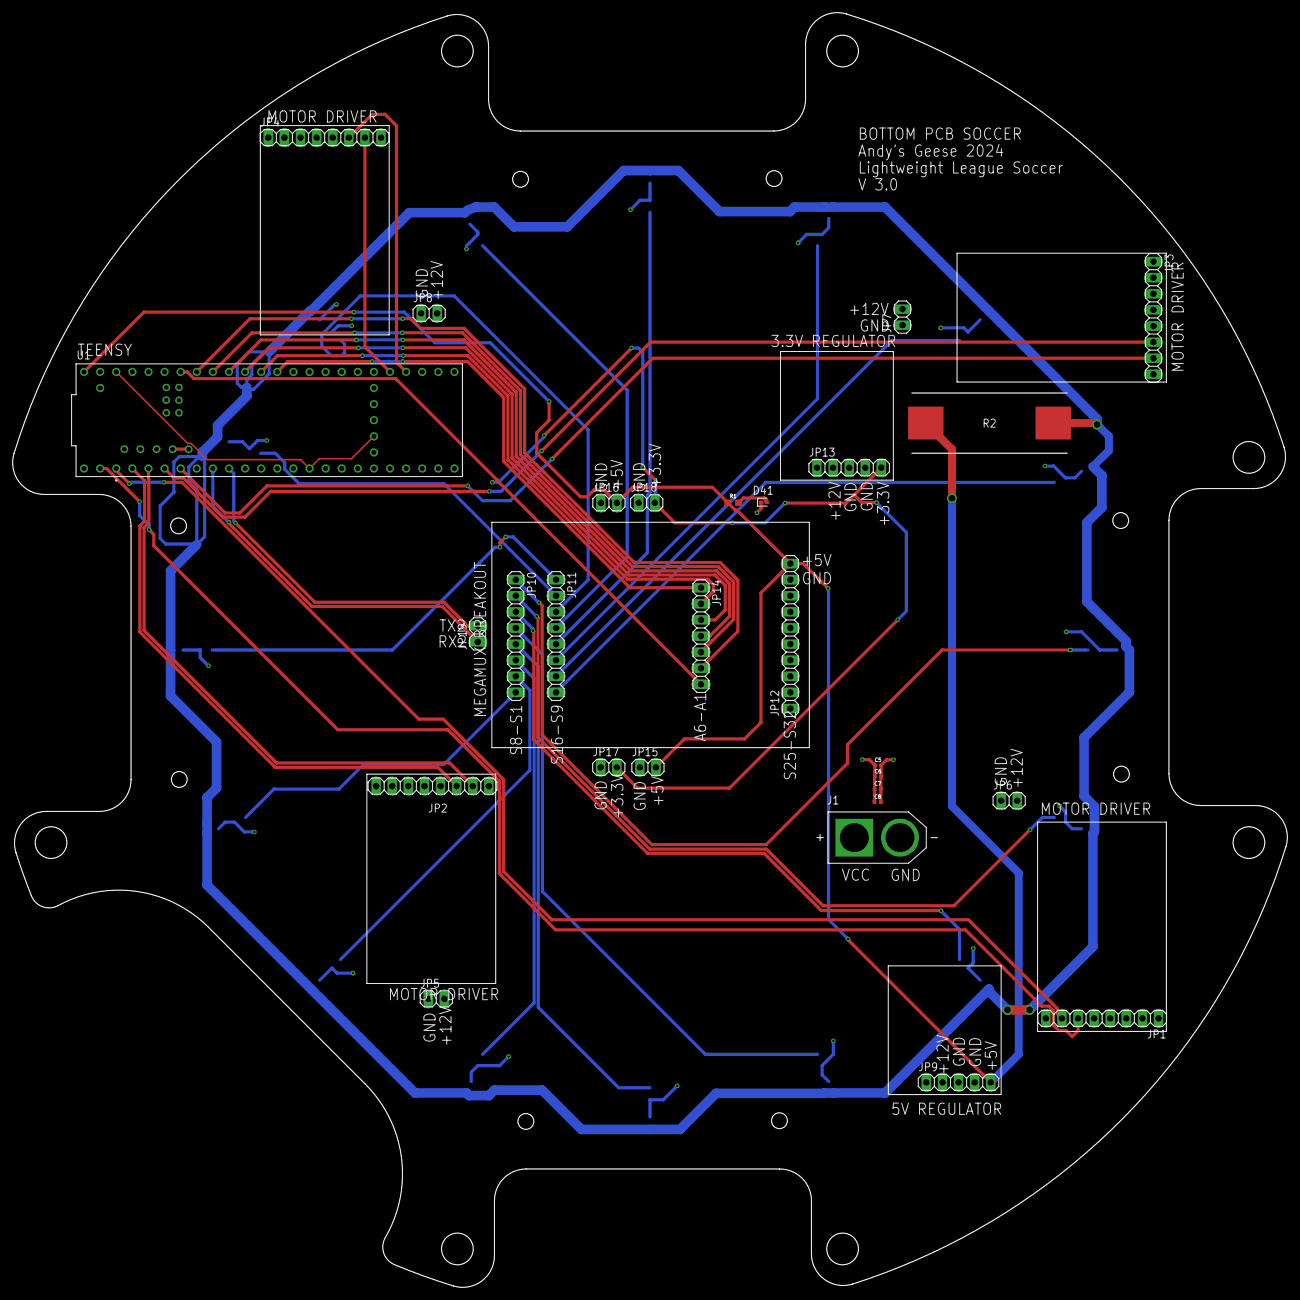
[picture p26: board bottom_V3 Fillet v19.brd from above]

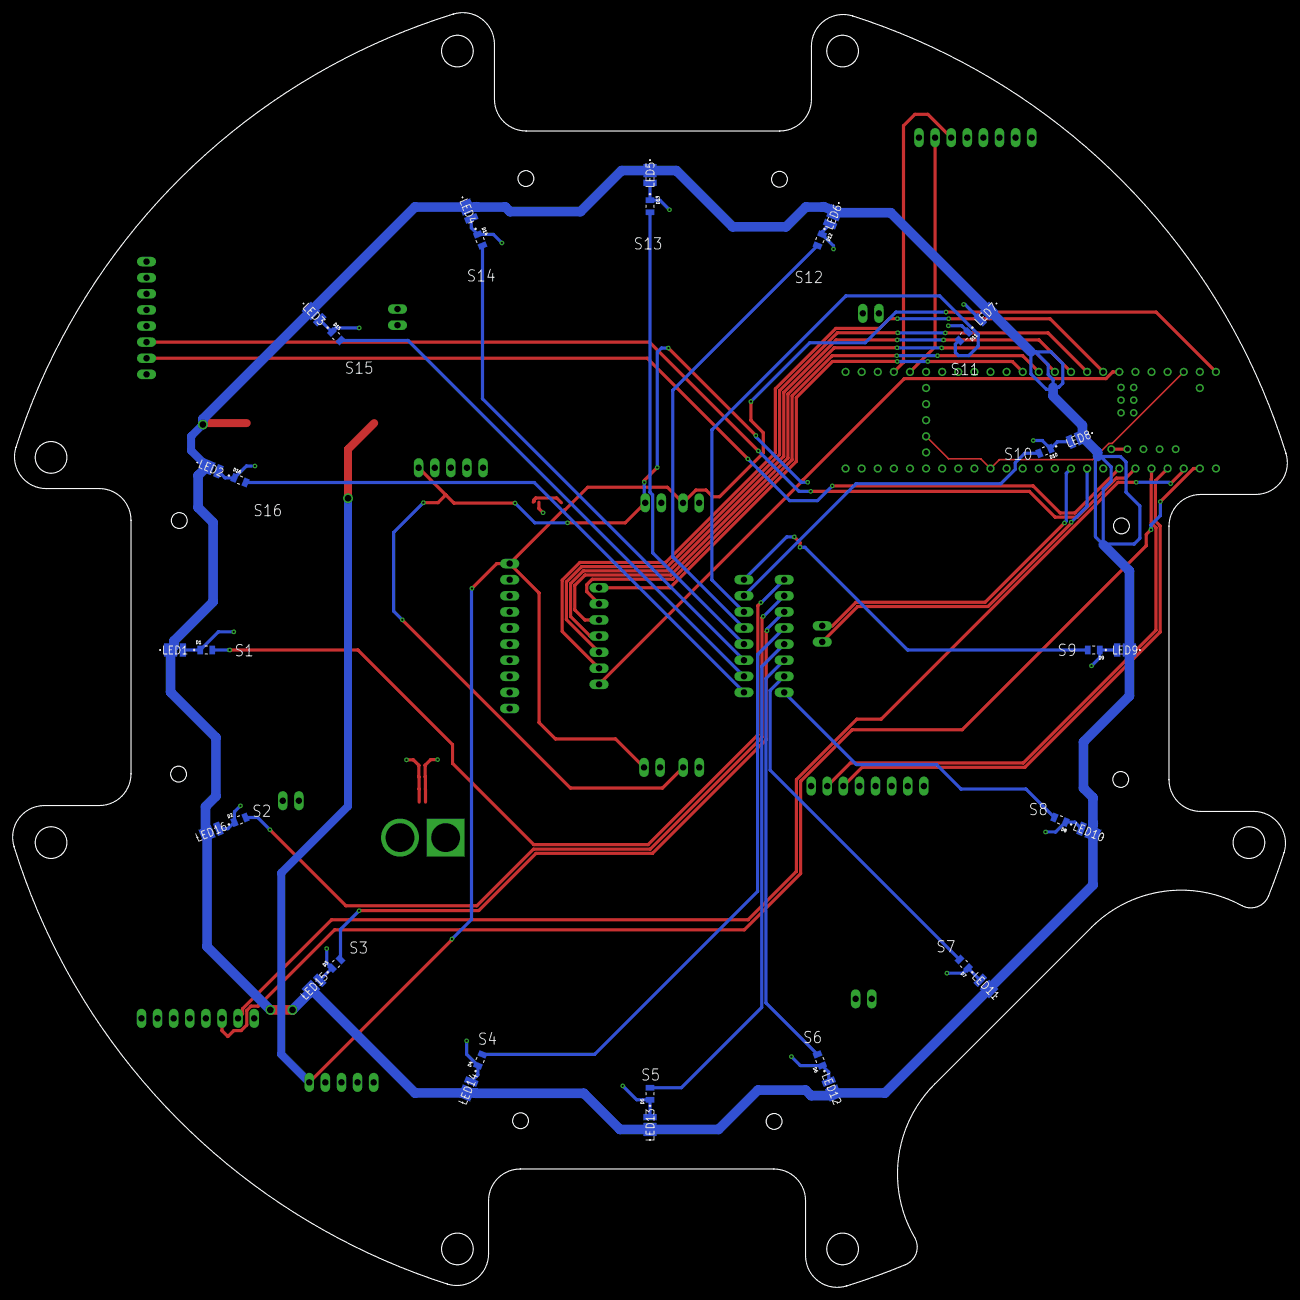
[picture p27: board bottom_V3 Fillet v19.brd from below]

Board: 4 copper layers, 201.1 x 201.1 mm, 60 parts (32 on the bottom side), 41 nets.

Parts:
C5, C6, C7, C8: 0.1uF; 0402-TIGHT
D1, D2, D3, D4, D5, D6, D7, D8, D9, D10, D11, D12, D13, D14, D15, D16: 019-141-411-R; DIOC2012X80N
D41: LED_GREEN; LEDC1005X25N_FLAT-G
J1: XT60-M; AMASS_XT60-M
JP1, JP2, JP3, JP4, JP10, JP11: PINHD-1X8; 1X08
JP5, JP6, JP7, JP8, JP15, JP16, JP17, JP18, JP19: PINHD-1X2; 1X02
JP9, JP13: PINHD-1X5; 1X05
JP12: PINHD-1X10; 1X10
JP14: PINHD-1X7; 1X07
LED1, LED2, LED3, LED4, LED5, LED6, LED7, LED8, LED9, LED10, LED11, LED12, LED13, LED14, LED15, LED16: 150283HS73103
R1: 1k; 0603
R2: SMW71R5JT; RESM24595X990N
U1: DEV-16771; MODULE_DEV-16771

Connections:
0: JP1.6, U1.0
1: JP1.7, U1.1
2: JP2.6, U1.2
3: JP2.7, U1.3
3.3V: U1.3.3V_1, U1.3.3V_2, U1.3.3V_3
4: JP3.6, U1.4
5: JP3.7, U1.5
36: JP4.6, U1.36
37: JP4.7, U1.37
+3.3V: JP13.5, JP17.2, JP18.2
+5V: JP9.5, JP12.10, JP15.2, JP16.2, R1.1, R2.1, U1.VIN
A0: JP14.1, U1.14
A1: JP14.2, U1.15
A2: JP14.3, U1.16
A3: JP14.4, U1.17
A4: JP14.5, U1.18
A5: JP14.6, U1.19
A6: JP14.7, U1.20
GND: C5.2, C6.2, C7.2, C8.2, D1.K, D2.K, D3.K, D4.K, D5.K, D6.K, D7.K, D8.K, D9.K, D10.K, D11.K, D12.K, D13.K, D14.K, D15.K, D16.K, D41.C, J1.N, JP1.8, JP2.8, JP3.8, JP4.8, JP5.1, JP6.1, JP7.1, JP8.1, JP9.3, JP9.4, JP12.9, JP13.3, JP13.4, JP15.1, JP16.1, JP17.1, JP18.1, LED1.2, LED2.2, LED3.2, LED4.2, LED5.2, LED6.2, LED7.2, LED8.2, LED9.2, LED10.2, LED11.2, LED12.2, LED13.2, LED14.2, LED15.2, LED16.2, U1.GND1, U1.GND2, U1.GND3, U1.GND4, U1.GND5
unnamed: LED1.1, LED2.1, LED3.1, LED4.1, LED5.1, LED6.1, LED7.1, LED8.1, LED9.1, LED10.1, LED11.1, LED12.1, LED13.1, LED14.1, LED15.1, LED16.1, R2.2
unnamed: D41.A, R1.2
RX2: JP19.1, U1.7
S1: D1.A, JP10.1
S2: D2.A, JP10.2
S3: D3.A, JP10.3
S4: D4.A, JP10.4
S5: D5.A, JP10.5
S6: D6.A, JP10.6
S7: D7.A, JP10.7
S8: D8.A, JP10.8
S9: D9.A, JP11.1
S10: D10.A, JP11.2
S11: D11.A, JP11.3
S12: D12.A, JP11.4
S13: D13.A, JP11.5
S14: D14.A, JP11.6
S15: D15.A, JP11.7
S16: D16.A, JP11.8
TX2: JP19.2, U1.8
USB_GND: U1.USB_GND1, U1.USB_GND2
VCC: C5.1, C6.1, C7.1, C8.1, J1.P, JP5.2, JP6.2, JP7.2, JP8.2, JP9.2, JP13.2

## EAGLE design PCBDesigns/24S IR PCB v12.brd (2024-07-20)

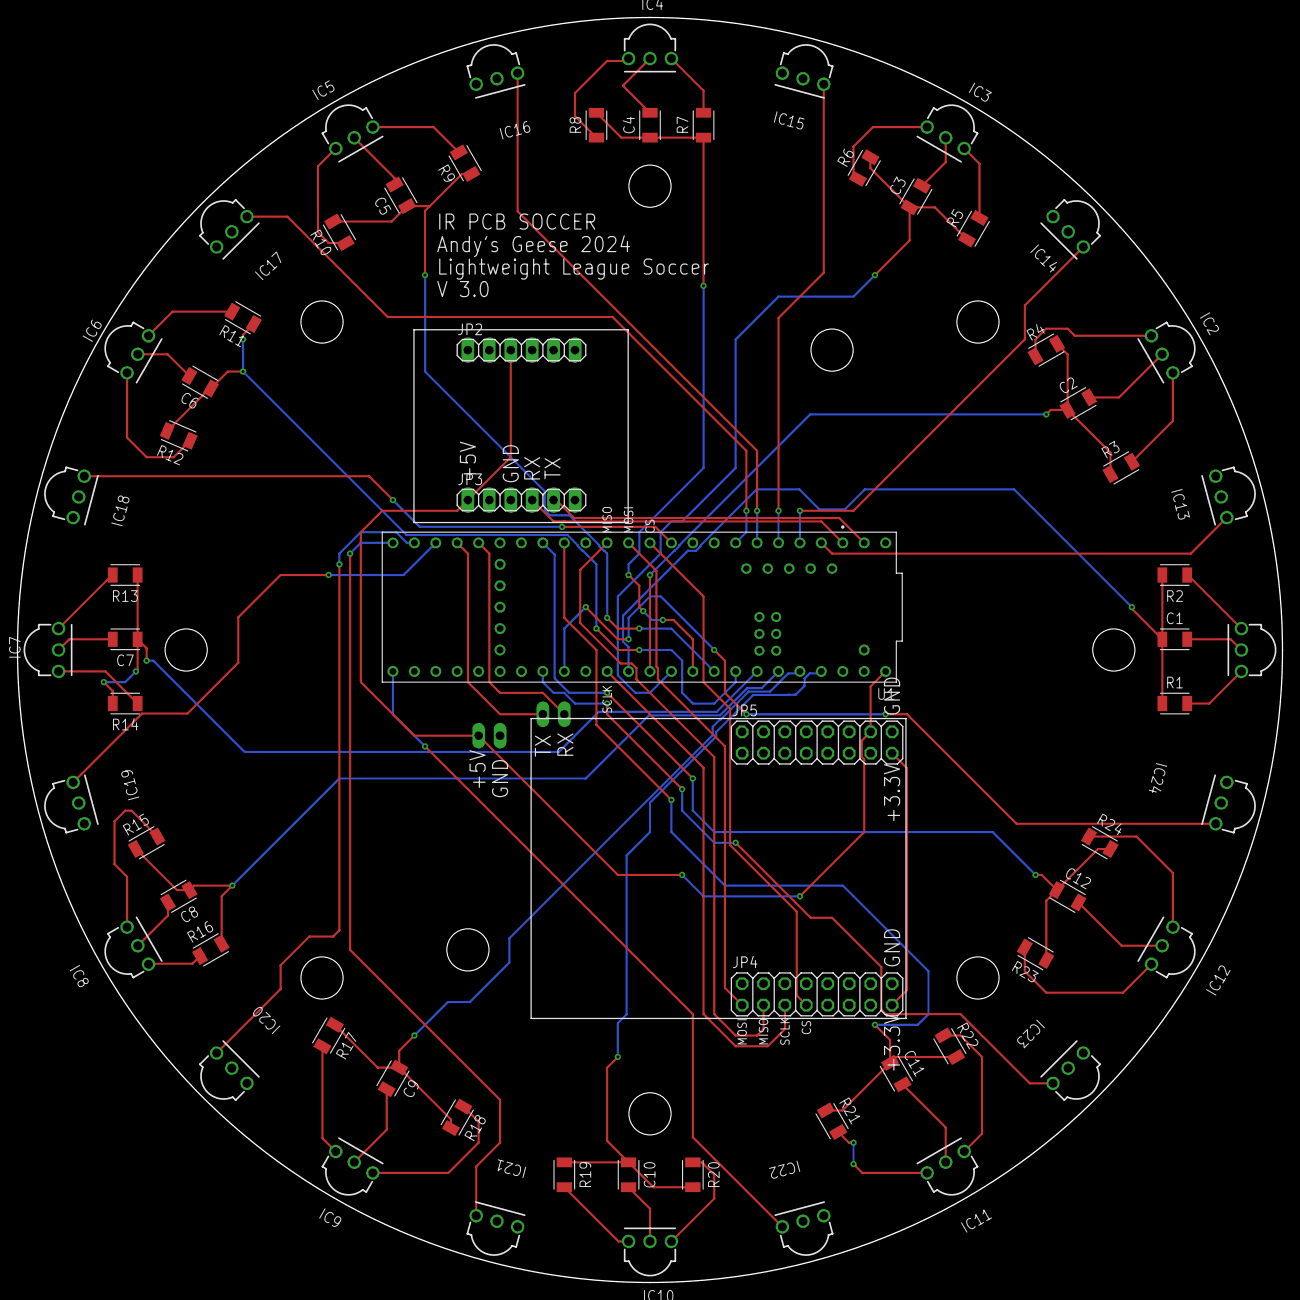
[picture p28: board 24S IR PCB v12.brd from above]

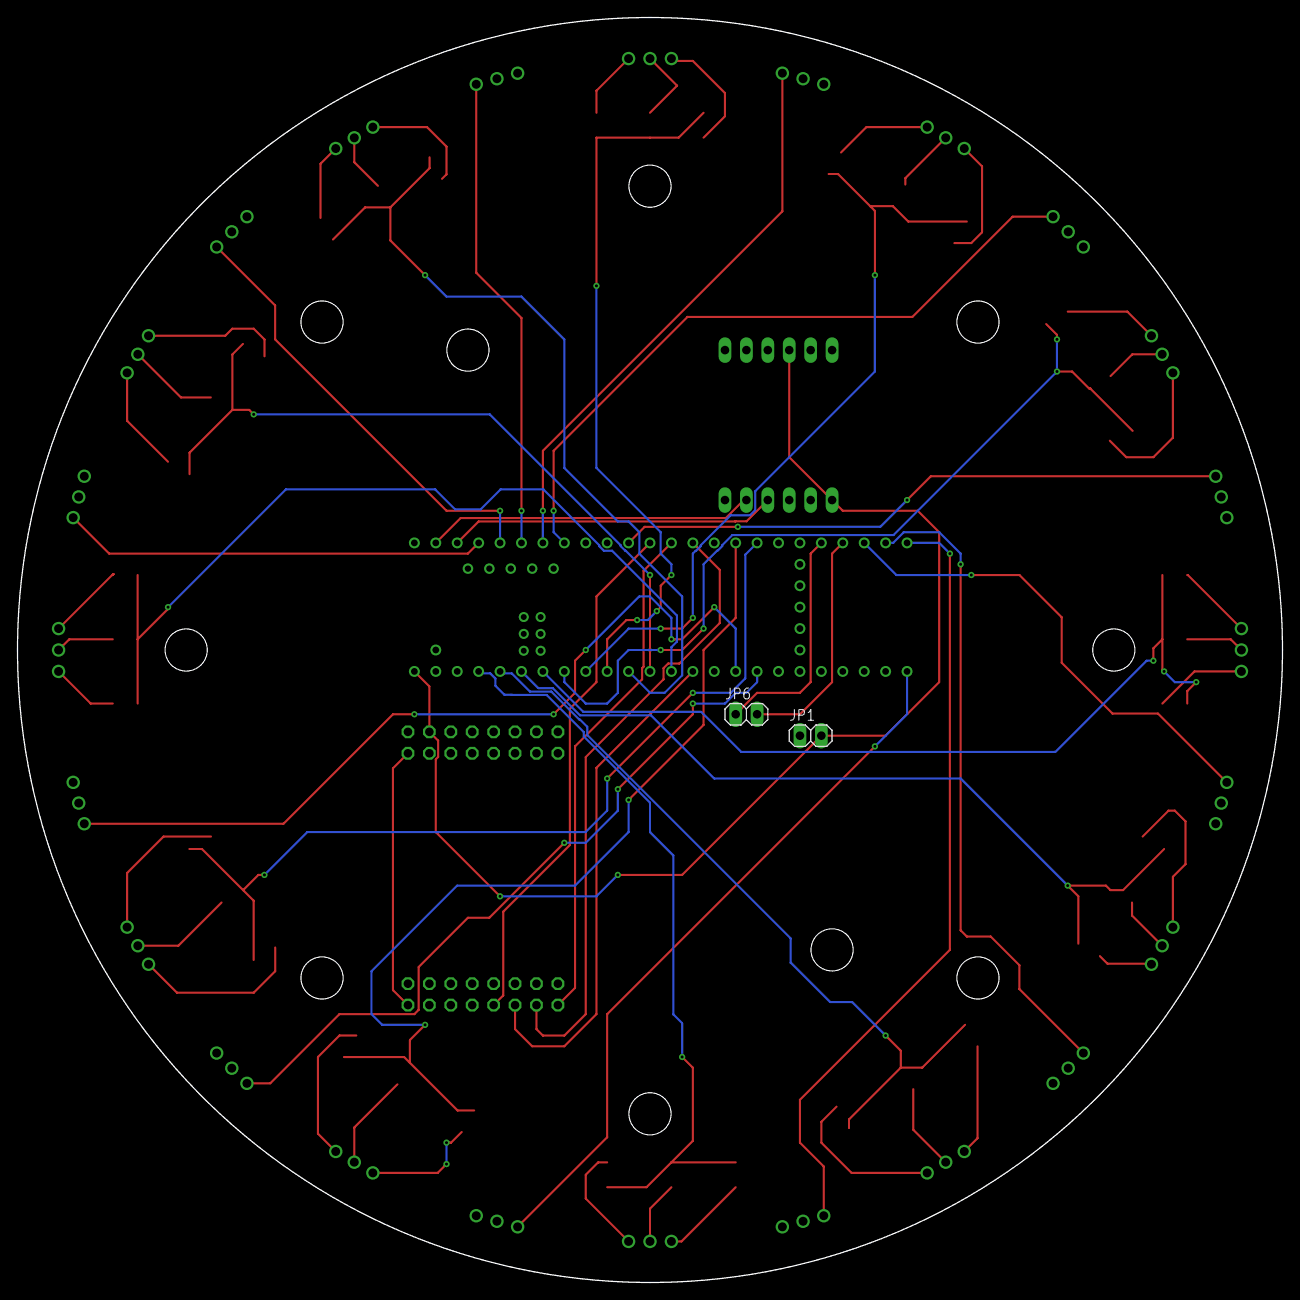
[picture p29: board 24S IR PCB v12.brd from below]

Board: 4 copper layers, 150.0 x 150.0 mm, 67 parts (2 on the bottom side), 48 nets.

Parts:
C1, C2, C3, C4, C5, C6, C7, C8, C9, C10, C11, C12: 4.7uF; CAPC3216X135
IC1, IC2, IC3, IC4, IC5, IC6, IC7, IC8, IC9, IC10, IC11, IC12, IC13, IC14, IC15, IC16, IC17, IC18, IC19, IC20, IC21, IC22, IC23, IC24: TSSP4038
JP1, JP6: PINHD-1X2; 1X02
JP2, JP3: PINHD-1X6; 1X06
JP4, JP5: PINHD-2X8; 2X08
R1, R3, R5, R7, R9, R11, R13, R15, R17, R19, R21, R23: 220; RESC3216X70
R2, R4, R6, R8, R10, R12, R14, R16, R18, R20, R22, R24: 10k; RESC3216X70
U1: DEV-16771; MODULE_DEV-16771

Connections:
3.3VRAIL: JP4.15, JP5.15
3V3: IC1.3, IC2.3, IC3.3, IC4.3, IC5.3, IC6.3, IC7.3, IC8.3, IC9.3, IC10.3, IC11.3, IC12.3, IC13.3, IC14.3, IC15.3, IC16.3, IC17.3, IC18.3, IC19.3, IC20.3, IC21.3, IC22.3, IC23.3, IC24.3, R2.1, R4.1, R6.1, R8.1, R10.1, R12.1, R14.1, R16.1, R18.1, R20.1, R22.1, R24.1, U1.3.3V_1, U1.3.3V_2, U1.3.3V_3
+5V: JP1.2, JP2.3, JP3.1, JP5.14, U1.VIN
GND: C1.2, C2.2, C3.2, C4.2, C5.2, C6.2, C7.2, C8.2, C9.2, C10.2, C11.2, C12.2, IC1.2, IC2.2, IC3.2, IC4.2, IC5.2, IC6.2, IC7.2, IC8.2, IC9.2, IC10.2, IC11.2, IC12.2, IC13.2, IC14.2, IC15.2, IC16.2, IC17.2, IC18.2, IC19.2, IC20.2, IC21.2, IC22.2, IC23.2, IC24.2, JP1.1, JP3.3, JP4.16, JP5.16, U1.GND1, U1.GND2, U1.GND3, U1.GND4, U1.GND5, U1.USB_GND1, U1.USB_GND2
unnamed: IC12.1, R23.2
unnamed: IC1.1, R1.2
unnamed: IC2.1, R3.2
unnamed: IC3.1, R5.2
unnamed: IC4.1, R7.2
unnamed: IC5.1, R9.2
unnamed: IC6.1, R11.2
unnamed: IC7.1, R13.2
unnamed: IC8.1, R15.2
unnamed: IC9.1, R17.2
unnamed: IC10.1, R19.2
unnamed: IC11.1, R21.2
P0: JP4.1, U1.11
P1: JP4.3, U1.12
P2: JP4.5, U1.13
P3: JP4.7, U1.10
RX: JP6.1, U1.28
SCL: JP3.4, U1.1
SDA: JP3.5, U1.0
TSSP1: C1.1, R1.1, R2.2, U1.14
TSSP2: C2.1, R3.1, R4.2, U1.15
TSSP3: C3.1, R5.1, R6.2, U1.16
TSSP4: C4.1, R7.1, R8.2, U1.17
TSSP5: C5.1, R9.1, R10.2, U1.18
TSSP6: C6.1, R11.1, R12.2, U1.19
TSSP7: C7.1, R13.1, R14.2, U1.20
TSSP8: C8.1, R15.1, R16.2, U1.21
TSSP9: C9.1, R17.1, R18.2, U1.22
TSSP10: C10.1, R19.1, R20.2, U1.23
TSSP11: C11.1, R21.1, R22.2, U1.24
TSSP12: C12.1, R23.1, R24.2, U1.25
TSSP13: IC13.1, U1.2
TSSP14: IC14.1, U1.3
TSSP15: IC15.1, U1.4
TSSP16: IC16.1, U1.5
TSSP17: IC17.1, U1.6
TSSP18: IC18.1, U1.9
TSSP19: IC19.1, U1.30
TSSP20: IC20.1, U1.31
TSSP21: IC21.1, U1.32
TSSP22: IC22.1, U1.33
TSSP23: IC23.1, U1.40
TSSP24: IC24.1, U1.41
TX: JP6.2, U1.29

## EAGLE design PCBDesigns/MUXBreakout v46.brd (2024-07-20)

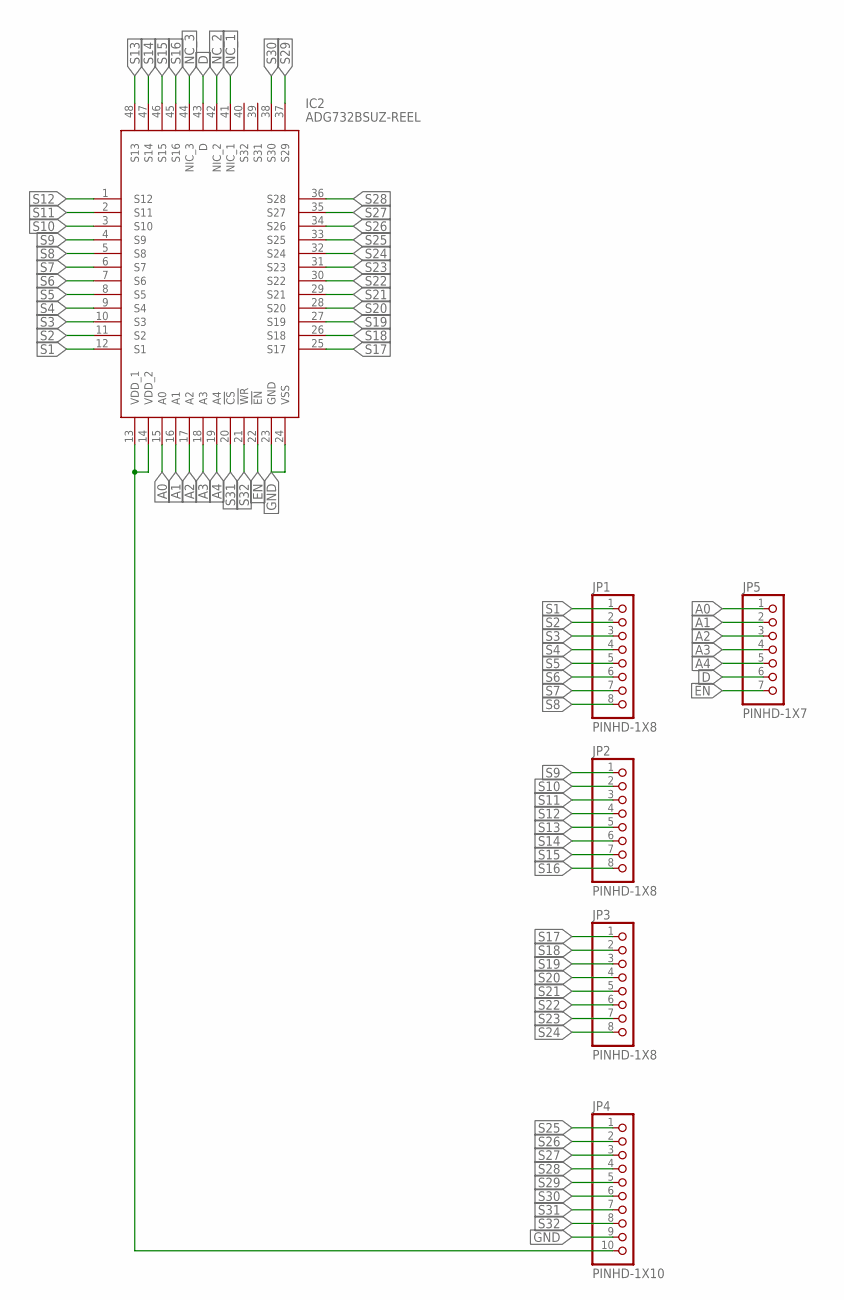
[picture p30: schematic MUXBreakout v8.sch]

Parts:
IC2: ADG732BSUZ-REEL; QFP50P900X900X120-48N
JP1, JP2, JP3: PINHD-1X8; 1X08
JP4: PINHD-1X10; 1X10
JP5: PINHD-1X7; 1X07

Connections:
!EN: IC2.22 (!EN), JP5.7
A0: IC2.15 (A0), JP5.1
A1: IC2.16 (A1), JP5.2
A2: IC2.17 (A2), JP5.3
A3: IC2.18 (A3), JP5.4
A4: IC2.19 (A4), JP5.5
D: IC2.43 (D), JP5.6
GND: IC2.23 (GND), IC2.24 (VSS), JP4.9
NC_1: IC2.41 (NIC_1)
NC_2: IC2.42 (NIC_2)
NC_3: IC2.44 (NIC_3)
S1: IC2.12 (S1), JP1.1
S2: IC2.11 (S2), JP1.2
S3: IC2.10 (S3), JP1.3
S4: IC2.9 (S4), JP1.4
S5: IC2.8 (S5), JP1.5
S6: IC2.7 (S6), JP1.6
S7: IC2.6 (S7), JP1.7
S8: IC2.5 (S8), JP1.8
S9: IC2.4 (S9), JP2.1
S10: IC2.3 (S10), JP2.2
S11: IC2.2 (S11), JP2.3
S12: IC2.1 (S12), JP2.4
S13: IC2.48 (S13), JP2.5
S14: IC2.47 (S14), JP2.6
S15: IC2.46 (S15), JP2.7
S16: IC2.45 (S16), JP2.8
S17: IC2.25 (S17), JP3.1
S18: IC2.26 (S18), JP3.2
S19: IC2.27 (S19), JP3.3
S20: IC2.28 (S20), JP3.4
S21: IC2.29 (S21), JP3.5
S22: IC2.30 (S22), JP3.6
S23: IC2.31 (S23), JP3.7
S24: IC2.32 (S24), JP3.8
S25: IC2.33 (S25), JP4.1
S26: IC2.34 (S26), JP4.2
S27: IC2.35 (S27), JP4.3
S28: IC2.36 (S28), JP4.4
S29: IC2.37 (S29), JP4.5
S30: IC2.38 (S30), JP4.6
S31: IC2.20 (!CS), JP4.7
S32: IC2.21 (!WR), JP4.8
VDD_2: IC2.13 (VDD_1), IC2.14 (VDD_2), JP4.10

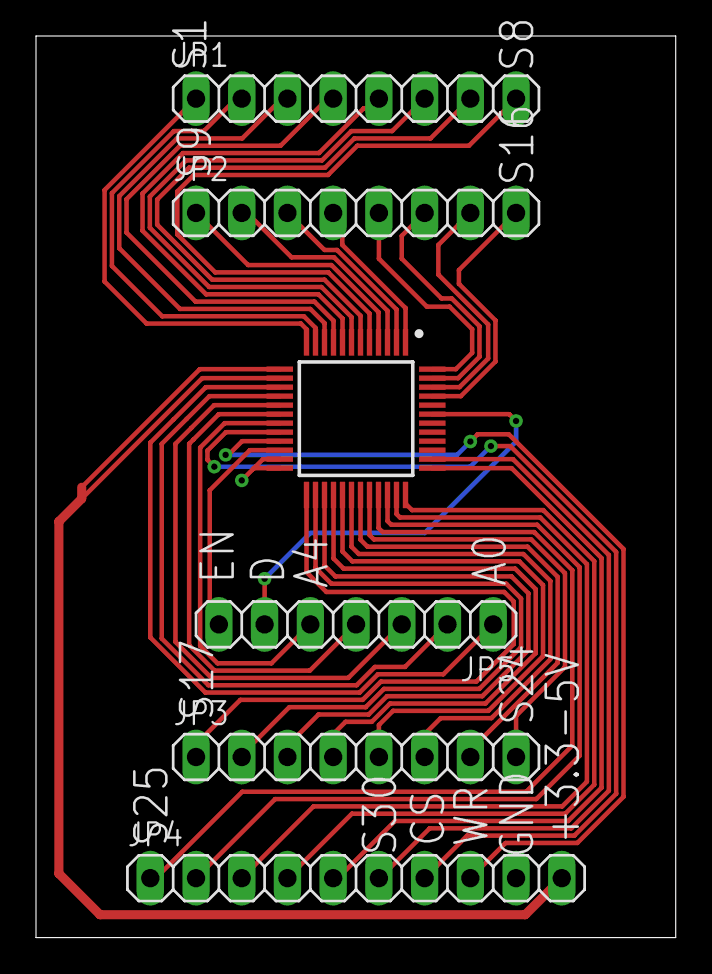
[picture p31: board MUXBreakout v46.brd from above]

Board: 2 copper layers, 35.5 x 50.1 mm, 6 parts (0 on the bottom side), 41 nets.

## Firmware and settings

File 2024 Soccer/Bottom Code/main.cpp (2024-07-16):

#include "motorControlV3.h"
#include "colorSensorV3.h"


Motor motorController;

//information from top
float robotAngle, ballDistance, ballAngle, netAngle;
//prev info from top
float pastNetAng;



//-------------------------PID-----------------------------------
//time for PID
int millisZero, currentMillis, pastMillis;
//final motor values
int motorValues[4];

//MOVEMENT PID
//movement pid constants --- CHANGE TO MAKE GOOD MOVEMENT (generally keep all between 0.00 - 1.00)
float kPMovement[4] = {0.8, 0.8, 0.8, 0.8}, kIMovement[4] = {0.2, 0.2, 0.2, 0.2}, kDMovement[4] = {0.05, 0.05, 0.05, 0.05};
//previous ball error values
int pastBallErrors[4] = {0, 0, 0, 0};
//movmement error sum 
int iMovementErrors[4];

//ANGLE PID 
//angle pid constants --- CHANGE TO MAKE GOOD MOVEMENT (generally keep all between 0.00 - 1.00)
float kPAngle = 0.8, kIAngle = 0.1, kDAngle = 0.05;
//previous ball error value
int pastAngleError = 0;
//angle error sum
int iAngleError = 0;
//previous error type
bool seesCamera;

//------------------------------------------------------------
//MOVEMENT
bool isRotatingClockwise;


//COMMUNICATION
byte information[5];
//Allows the top and bottom boards to recieve info properly
//Needs to be run at top of communication in loop
void sync() {
    byte check[5];
    int shift=0;
    if(Serial2.available() > 4) {
        Serial2.readBytes(check, 5);
    }

    for (int i=0; i<5; i++) {
        if (check[i] == 255) {
            shift = i;
        }
    }

    // if (shift > 0) {
    //     shift -= 1;
    // }

    for (int i=0; i<shift; i++) {
        Serial2.read();
    }

}

//if type == 1 (robot angle), type == 2 (ir ball)
//Finds the error when you are using an angle
//Makes up from the edge case from 0 - 360
int calculateAngleError(int desiredDegrees, int actualDegrees, int type) {
    int error = desiredDegrees - actualDegrees;

    switch(type) {
    case 1:
        if (error > 180) {
            error -= 360;
        } 
        else if (error < -180) {
            error += 360;
        }
    case 2:
        if (error > 360) {
            error -= 360;
        } 
        else if (error < 0) {
            error += 360;
        }
    }

    return error;
}

int unpackData(int value, int type) {
    int info = -1;
    if(type == 1) {
        info = map(value, 0, 250, -180, 180);
    }
    //not done
    else if(type == 2) {
        info = value;
    }
    else if(type == 3) {
        info = map(value, 0, 250, 0, 360);
    }
    else if(type == 4) {
        if(value != 253) {
            pastNetAng = netAngle;
            value = 0;
        }
        else if (value == 0) {
            value = pastNetAng;
        }

        info = map(value, 1, 250, -50, 50);
    }
    return info;
}

//Full PID code for movement
//motor is the motor 1...4 that is speed is being set, isMovingClockwise tells if you want to move clockwise or counter around the ball
// speed is the max speed, or amplitude of the sine wave, ballAngle is the direction in which the ball is facing from the bot 

int movementPID(int motor, bool isMovingClockwise, int speed, float ballAngle) {
    float ballError = calculateAngleError(0, ballAngle, 1);
    
    int motorValue = motorController.movementSineFunction(motor, ballAngle, isMovingClockwise, speed);

    //Add movement error to sum
    iMovementErrors[motor] += ballError * (currentMillis - pastMillis);
    int pMovementValue = kPMovement[motor] * ballError;
    int iMovementValue = kIMovement[motor] * iMovementErrors[motor];
    int dMovementValue = kDMovement[motor] * ((ballError - pastBallErrors[motor])/(currentMillis - pastMillis));
    int pidValue = pMovementValue + iMovementValue + dMovementValue;

    motorValue *= pidValue;

    //SHOULD NOT BE USED FOR NOW
    // if(motorValue > 0 && motorValue < 30) {
    //     motorValue += 30;
    // }
    // else if(motorValue < 0 && motorValue > -30) {
    //     motorValue -= 30;
    // }

    //sets past angle errors to current errors
    pastBallErrors[motor] = ballError;
    return motorValue;
}

//camera == true means that it sees the camera 
//returns the motor values to allow the robot to be in middle of net (if net is seen), or face forward
//float angle is the angle of the net (-50 - 50) or bot angle (-180 - 180)
int anglePID(float angle, bool camera) {
    float angleError;
    //The angle you wish to face
    float desiredAngle = 0;
    if(camera) {
        angleError = desiredAngle - angle;
    }
    else {
        angleError = calculateAngleError(desiredAngle, angle, 1);
    }

    //Add angle error to sum
    iAngleError += angleError * currentMillis;
    int pAngleValue = kPAngle * angleError;
    int iAngleValue = kIAngle * iAngleError;
    int dAngleValue = kDAngle * ((angleError - pastAngleError)/(currentMillis - pastMillis));
    int pidValue = pAngleValue + iAngleValue + dAngleValue;

    return pidValue;
}

// int rotationPID(int motor, )

void setup() {
    Serial.begin(20000000);
    Serial2.begin(20000000);

    // colourSensor.init();
    motorController.init();
    millisZero = millis();
    currentMillis = millisZero;
}


void loop() {
    //communication
    sync();

    if(Serial2.available() > 4) {
        Serial2.readBytes(information, 5);
    }

    robotAngle = unpackData(information[1], 1);
    ballDistance = unpackData(information[2], 2);
    ballAngle = unpackData(information[3], 3);
    netAngle = unpackData(information[4], 4);
    
    Serial.println(ballAngle);

    //movement
    pastMillis = currentMillis;
    currentMillis = millis();
    // isRotatingClockwise = true;
    for(int i = 0; i < 4; i++) {
        motorValues[i] = movementPID(i+1, false, 50, ballAngle);
    }

    motorController.moveRobot(motorValues[0], motorValues[1], motorValues[2], motorValues[3]);
    // motorController.moveRobot(100, 100, -100, -100);
    // for(int i = 0; i < 4; i++) {
    //     Serial.print(" ");
    //     Serial.print(i);
    //     Serial.print(": ");
    //     Serial.print(motorValues[i]);
    // }
    // Serial.println();
}   

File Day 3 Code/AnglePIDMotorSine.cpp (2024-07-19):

#include <Arduino.h>
#include "motorControlV3.h"
#include "RunningMedian.h"

Motor motorController;

//information from top
float robotAngle, ballDistance, ballAngle, netAngle;
//prev info from top
float pastNetAng;
//count if camera does not see
int cameraSeesCount;
//robot on green
bool onGreen = false;

//overall speed
int overallSpeed = 80;

//-------------------------PID-----------------------------------
//time for PID
int millisZero, currentMillis, pastMillis;
double changeTime;
//final motor values
int motorValues[4];


//MOVEMENT PID
//movement pid constants --- CHANGE TO MAKE GOOD MOVEMENT (generally keep all between 0.00 - 1.00)
float kPMovement[4] = {0.05, 0.05, 0.05, 0.05}, kIMovement[4] = {0.000, 0.000, 0.000, 0.000}, kDMovement[4] = {0.002, 0.002, 0.002, 0.002}; //0.005
//previous ball error values
float pastBallError = 0.0;
//movmement error sum 
float iMovementError = 0.0;
//current ball error
float ballError = 0.0;
//change of error for all motors
float dMovementError = 0.0;

//ANGLE PID 
//angle pid constants --- CHANGE TO MAKE GOOD MOVEMENT (generally keep all between 0.00 - 1.00)
float kPAngle = 0.9, kIAngle = 0.0, kDAngle = 0.000;
//previous ball error value
float pastAngleError = 0;
//angle error sum
float iAngleError = 0;
//previous error type
bool seesCamera;

//------------------------------------------------------------
//MOVEMENT
bool isRotatingClockwise;
//Switch between rotating and moving each loop
bool isRotating = false;


//COMMUNICATION
byte information[5];

const int BUTTON_PIN = 13;

//Allows the top and bottom boards to recieve info properly
//Needs to be run at top of communication in loop
void sync() {
    byte check[5];
    int shift=0;
    if(Serial2.available() > 4) {
        Serial2.readBytes(check, 5);
    }

    for (int i=1; i<6; i++) {
        if (check[i] == 255) {
            shift += i;
        }
        else {
            break;

        }
    }


    for (int i=0; i<shift; i++) {
        Serial2.read();
    }

}


//if type == 1 (robot angle), type == 2 (ir ball), type == 3 (colour +/- 90)
//Finds the error when you are using an angle
//Makes up from the edge case from 0 - 360
float calculateAngleError(float desiredDegrees, float actualDegrees, int type) {
    float error = desiredDegrees - actualDegrees;

    switch(type) {
    case 1:
        if (error > 180) {
            error -= 360;
        } 
        else if (error < -180) {
            error += 360;
        }
        break;
    case 2:
        if (error > 180) {
            error -= 360;
        } 
        else if (error < -180) {
            error += 360;
        }
        break;
    }

    return error;
}

//if type == 1 (robot angle), type == 2 (ir ball), type (colour +/- 90) with isColourChangePositive
//Finds the error when you are using an angle
//Makes up from the edge case from 0 - 360
// float calculateAngleError(float desiredDegrees, float actualDegrees, int type, bool isColourChangePositive) {
//     float error = desiredDegrees - actualDegrees;

//     if() {
//     }

//     return error;
// }

int unpackData(int value, int type) {
    int info = -1;
    if(type == 1) {
        info = map(value, 0, 250, -180, 180);
    }
    //not done
    else if(type == 2) {
        info = value;
    }
    else if(type == 3) {
        info = map(value, 0, 250, 0, 359);
    }
    else if(type == 4) {
        if(value != 253) {
            pastNetAng = netAngle;
            value = 0;
            cameraSeesCount = 0;
        }
        else if (value == 0) {
            value = pastNetAng;
            cameraSeesCount += 1;
        }

        info = value;//map(value, 1, 250, -50, 50);
    }
    return info;
}

//Full PID code for movement
//motor is the motor 1...4 that is speed is being set, isMovingClockwise tells if you want to move clockwise or counter around the ball
// speed is the max speed, or amplitude of the sine wave, ballAngle is the direction in which the ball is facing from the bot 

float movementPID(int motor, bool isMovingClockwise, int speed, float ballAngle) {
    float motorValue = motorController.movementSineFunction(motor, ballAngle, isMovingClockwise, speed);

    // Serial.print("Sine calc: ");
    // Serial.println(motorValue);

    // motorValue *= kPMovement[motor] * ballError + kIMovement[motor] * iMovementError + kDMovement[motor] * dMovementError;

    // Serial.print("Motor + PID: ");
    // Serial.println(motorValue);

    //SHOULD NOT BE USED FOR NOW
    // if(motorValue > 0 && motorValue < 30) {
    //     motorValue += 30;
    // }
    // else if(motorValue < 0 && motorValue > -30) {
    //     motorValue -= 30;
    // }

    return motorValue;
}

//This function is a "child" of movement sine but creates a vector of movement normal to line if it 
//is seen. The parameters are the same as movement sine with the addition of colourDirection which
//is -1.0 if line is not seen and 0.0-360.0 in the direction of the line
//Outputs -1 if not working 
int movementSineColour(int motor, float ballAngleDegrees, bool isCounter, float amplitude, float colourDirection) {
    int motorValue = -1;
    motorValue = motorController.movementSineFunction(motor, ballAngleDegrees, isCounter, amplitude);

    if(calculateAngleError() &&  )
    return motorValue;
}

//camera == true means that it sees the camera 
//returns the motor values to allow the robot to be in middle of net (if net is seen), or face forward
//float angle is the angle of the net (-50 - 50) or bot angle (-180 - 180)
float anglePID(float angle, bool camera) {
    float angleError;
    //The angle you wish to face
    float desiredAngle = 0;
    if(camera) {
        angleError = desiredAngle - angle;
    }
    else {
        angleError = calculateAngleError(desiredAngle, angle, 1);
    }

    //Add angle error to sum
    // iAngleError += angleError * (changeTime/100.0);
    // Serial.print("ANGLE ERROR: ");
    // Serial.println(angleError);
    // Serial.print("I ERROR: ");
    // Serial.println(iAngleError);
    float pAngleValue = kPAngle * angleError;
    // Serial.print("pAngleValue: ");
    // Serial.println(pAngleValue);
    // float iAngleValue = kIAngle * iAngleError;
    // // Serial.print("iAngleValue: ");
    // // Serial.println(iAngleValue);
    // float dAngleValue = kDAngle * ((angleError - pastAngleError)/(changeTime*10000000.0));
    // Serial.print("dAValue: ");
    // Serial.println(dAngleValue);
    float pidValue = pAngleValue;
    // Serial.print("PID VALUE: ");
    // Serial.println(pidValue);
    return pidValue;
}

void setup() {
    Serial2.begin(20000000); //115200 20000000
    sync();
    pinMode(BUTTON_PIN, INPUT);
    // colourSensor.init();
    motorController.init();
    millisZero = micros();
    currentMillis = millisZero; 
    // for (int i=0; i<1000; i++) { //100
    //     sync();  
    // }
}

int loops = 0;
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

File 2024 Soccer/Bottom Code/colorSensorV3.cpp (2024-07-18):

#include <Arduino.h>
#include <Wire.h>
#include <RunningMedian.h>
#include <Math.h>
#include "colorSensorV3.h"

//starts at 7, 6, ... 9, 8 for all 16 s 
int colourSensorValues[16];

const int numberSamples = 200;
const int differenceBetweenGreenAndWhite = 2;
RunningMedian greenValues[16] = {RunningMedian(numberSamples), RunningMedian(numberSamples), RunningMedian(numberSamples), RunningMedian(numberSamples), 
    RunningMedian(numberSamples), RunningMedian(numberSamples), RunningMedian(numberSamples), RunningMedian(numberSamples), RunningMedian(numberSamples), 
    RunningMedian(numberSamples), RunningMedian(numberSamples), RunningMedian(numberSamples), RunningMedian(numberSamples), RunningMedian(numberSamples), 
    RunningMedian(numberSamples), RunningMedian(numberSamples)};

int maximum = 0;

float percentageIncrease = 1.20;

bool isFilled = false;


ColorSensor::ColorSensor(){
}

void ColorSensor::init() {
    pinMode(A0, OUTPUT);
    pinMode(A1, OUTPUT);
    pinMode(A2, OUTPUT);
    pinMode(A3, OUTPUT);
    pinMode(A4, OUTPUT);
    fillMedians();
}


//sensor is different than pcb
//sensor starts at front (0) increases clockwise to 15 (looking from bottom)
int ColorSensor::readSensor(int sensor) {
    switch(sensor){
    case 0:   
        digitalWrite(A0, HIGH);
        digitalWrite(A1, HIGH);
        digitalWrite(A2, HIGH);
        digitalWrite(A3, LOW);
        digitalWrite(A4, LOW);
        digitalWrite(A6, LOW);
        break;
    case 1:
        digitalWrite(A0, LOW);
        digitalWrite(A1, HIGH);
        digitalWrite(A2, HIGH);
        digitalWrite(A3, LOW);
        digitalWrite(A4, LOW);
        digitalWrite(A6, LOW);
        break;
    case 2:
        digitalWrite(A0, HIGH);
        digitalWrite(A1, LOW);
        digitalWrite(A2, HIGH);
        digitalWrite(A3, LOW);
        digitalWrite(A4, LOW);
        digitalWrite(A6, LOW); 
        break;       
    case 3: 
        digitalWrite(A0, LOW);
        digitalWrite(A1, LOW);
        digitalWrite(A2, HIGH);
        digitalWrite(A3, LOW);
        digitalWrite(A4, LOW);
        digitalWrite(A6, LOW);
        break;
    case 4:
        digitalWrite(A0, HIGH);
        digitalWrite(A1, HIGH);
        digitalWrite(A2, LOW);
        digitalWrite(A3, LOW);
        digitalWrite(A4, LOW);
        digitalWrite(A6, LOW);
        break;
    case 5:
        digitalWrite(A0, LOW);
        digitalWrite(A1, HIGH);
        digitalWrite(A2, LOW);
        digitalWrite(A3, LOW);
        digitalWrite(A4, LOW);
        digitalWrite(A6, LOW);
        break;
    case 6:
        digitalWrite(A0, HIGH);
        digitalWrite(A1, LOW);
        digitalWrite(A2, LOW);
        digitalWrite(A3, LOW);
        digitalWrite(A4, LOW);
        digitalWrite(A6, LOW);
        break;
    case 7:
        digitalWrite(A0, LOW);
        digitalWrite(A1, LOW);
        digitalWrite(A2, LOW);
        digitalWrite(A3, LOW);
        digitalWrite(A4, LOW);
        digitalWrite(A6, LOW);
        break;
    case 8:
        digitalWrite(A0, HIGH);
        digitalWrite(A1, HIGH);
        digitalWrite(A2, HIGH);
        digitalWrite(A3, HIGH);
        digitalWrite(A4, LOW);
        digitalWrite(A6, LOW);
        break;
    case 9:
        digitalWrite(A0, LOW);
        digitalWrite(A1, HIGH);
        digitalWrite(A2, HIGH);
        digitalWrite(A3, HIGH);
        digitalWrite(A4, LOW);
        digitalWrite(A6, LOW);
        break;
    case 10:
        digitalWrite(A0, HIGH);
        digitalWrite(A1, LOW);
        digitalWrite(A2, HIGH);
        digitalWrite(A3, HIGH);
        digitalWrite(A4, LOW);
        digitalWrite(A6, LOW);
        break;
    case 11:
        digitalWrite(A0, LOW);
        digitalWrite(A1, LOW);
        digitalWrite(A2, HIGH);
        digitalWrite(A3, HIGH);
        digitalWrite(A4, LOW);
        digitalWrite(A6, LOW);
        break;
    case 12:
        digitalWrite(A0, HIGH);
        digitalWrite(A1, HIGH);
        digitalWrite(A2, LOW);
        digitalWrite(A3, HIGH);
        digitalWrite(A4, LOW);
        digitalWrite(A6, LOW);
        break;
    case 13:
        digitalWrite(A0, LOW);
        digitalWrite(A1, HIGH);
        digitalWrite(A2, LOW);
        digitalWrite(A3, HIGH);
        digitalWrite(A4, LOW);
        digitalWrite(A6, LOW);
        break;
    case 14:
        digitalWrite(A0, HIGH);
        digitalWrite(A1, LOW);
        digitalWrite(A2, LOW);
        digitalWrite(A3, HIGH);
        digitalWrite(A4, LOW);
        digitalWrite(A6, LOW);
    case 15:
        digitalWrite(A0, LOW);
        digitalWrite(A1, LOW);
        digitalWrite(A2, LOW);
        digitalWrite(A3, HIGH);
        digitalWrite(A4, LOW);
        digitalWrite(A6, LOW);
        break;
    }
	return analogRead(A5);
}

void ColorSensor::fillMedians() {
    for(int i = 0; i < numberSamples; i++) {
        for(int i = 0; i < 16; i++) {
            greenValues[i].add(readSensor(i));
        }
    }
    isFilled = true;
}

void ColorSensor::readSensors() {
    for (int i = 0; i < 16; i++) {
        colourSensorValues[i] = readSensor(i);
        if(colourSensorValues[i] < greenValues[i].getAverage() * percentageIncrease) {
            greenValues[i].add(colourSensorValues[i]);
        }
        else {
            Serial.print("bad ");
        }
        // Serial.print(greenValues[i].getAverage());
        // Serial.print(" ");
        // Serial.print(colourSensorValues[i]);
        // Serial.print(" ");
    }
    // Serial.println();
}

float ColorSensor::calculateDirection() {
    // readSensors();

    float sumCos = 0;
    float sumSin = 0;
    int activeSensors = 0;

    for (int i = 0; i < 16; i++) {
         colourSensorValues[i] = readSensor(i);
        if (colourSensorValues[i] > greenValues[i].getMedian()*1.1) {
            float angle = ((2 * PI) / 16) * i;
            sumCos += cos(angle);
            sumSin += sin(angle);
            activeSensors++;
        }
    }

    if (activeSensors == 0) {
        // No line detected
        return 0; // or some invalid value to indicate no detection
    }

    float avgCos = sumCos / activeSensors;
    float avgSin = sumSin / activeSensors;

    return atan2(avgSin, avgCos);

    //360 clockwise
    //2.55 sensor 0
    //-2.16 90
    //-0.79 180
    //0.98 270
    //if negative between 90 and 180
    //if positive between 0 and 270

    //from 1.191 to above 2: move back
    //from-2.40 to -1.5: move left
    //from -0.7 to -1.18 move forward
    //from 0.8 to 0.98 move right

}




void ColorSensor::visualize(){
    readSensors();
    for(int i = 0; i < 16; i++) {
        if(colourSensorValues[i] > int(greenValues[i].getMedian() * percentageIncrease)) Serial.print("_");
        else Serial.print("*");
	}
    Serial.println("");
}
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

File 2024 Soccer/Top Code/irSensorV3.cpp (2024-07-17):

//---------Libraries---------
#include "irSensorV3.h"
#include <RunningMedian.h>
#include <math.h>

//Setting up the RunningMedian for each Sensor
IRSensor::IRSensor() 
: s1Distance(sensorReadCount), s2Distance(sensorReadCount), s3Distance(sensorReadCount), s4Distance(sensorReadCount), s5Distance(sensorReadCount), s6Distance(sensorReadCount), s7Distance(sensorReadCount), s8Distance(sensorReadCount), s9Distance(sensorReadCount), s10Distance(sensorReadCount), s11Distance(sensorReadCount), s12Distance(sensorReadCount) {
}

//Putting all the RunningMedian into a array
const int numberMedianValues = 25;
RunningMedian sDistances[12] = {RunningMedian(numberMedianValues), RunningMedian(numberMedianValues), RunningMedian(numberMedianValues), 
RunningMedian(numberMedianValues), RunningMedian(numberMedianValues), RunningMedian(numberMedianValues),RunningMedian(numberMedianValues), 
RunningMedian(numberMedianValues), RunningMedian(numberMedianValues), RunningMedian(numberMedianValues), RunningMedian(numberMedianValues), 
RunningMedian(numberMedianValues)};


//-----------Variables------------
int lowestPin[numberMedianValues];
int IR_PINS[12] = {A11, A0, A1, A2, A3, A4, A5, A6, A7, A8, A9, A10};
//12, 1, 2, 3 ... 11
int sensorValues[12];


//------------  
void IRSensor::readSensors() {
    for (int i = 0; i < sensorReadCount; i++) {
        s1Distance.add(analogRead(A0));
        s2Distance.add(analogRead(A1));
        s3Distance.add(analogRead(A2));
        s4Distance.add(analogRead(A3));
        s5Distance.add(analogRead(A4));
        s6Distance.add(analogRead(A5));
        s7Distance.add(analogRead(A6));
        s8Distance.add(analogRead(A7));
        s9Distance.add(analogRead(A8));
        s10Distance.add(analogRead(A9));
        s11Distance.add(analogRead(A10));
        s12Distance.add(analogRead(A11));
    }

    sensorValues[0] = s1Distance.getMedian();
    sensorValues[1] = s2Distance.getMedian();
    sensorValues[2] = s3Distance.getMedian();
    sensorValues[3] = s4Distance.getMedian();
    sensorValues[4] = s5Distance.getMedian();
    sensorValues[5] = s6Distance.getMedian();
    sensorValues[6] = s7Distance.getMedian();
    sensorValues[7] = s8Distance.getMedian();
    sensorValues[8] = s9Distance.getMedian();
    sensorValues[9] = s10Distance.getMedian();
    sensorValues[10] = s11Distance.getMedian();
    sensorValues[11] = s12Distance.getMedian();
}

int IRSensor::findMinSensor() {
    readSensors();
    int min = 1e8;
    int minIndex = -1;
    for (int i = 0; i < 12; i++) {
        int cur = sensorValues[i];
        if (cur < min) {
            min = cur;
            minIndex = i;
        }
    }
    return minIndex;
}

int IRSensor::findBallDirection() {
    int averageCount= 100;
    double closestSensor;
    for (int i=0; i< averageCount;i++){
        closestSensor += findMinSensor();
    }
    closestSensor = closestSensor/averageCount;
    return (closestSensor + 1) * 30;
}

void IRSensor::printBallDirection() {
    Serial.print("Ball direction: ");
    Serial.println(findBallDirection());
}

void IRSensor::debugValues() {
    for(int i = 0; i < 12; i++) {
        Serial.print(i+1);
        Serial.print(": ");
        Serial.println(sensorValues[i]);
    }
}

  void IRSensor::debugComponents() {
    for(int i = 0; i < 12; i++) {
      Serial.print(i+1);
      Serial.print(": ");
      double angle = ((i+1) * 360.0) / 12.0; 
      double radians = angle * DEG_TO_RAD; 
      double x = sensorValues[i] * cos(radians);
      double y =  sensorValues[i] * sin(radians);
      Serial.print(x);
      Serial.print(" ");
      Serial.println(y);
    }
  }

  
float IRSensor::findSensorDistance(int sensor, int intensity) {
    float distance = -1;
    switch (sensor) {
        case 0:
            //  distance = 1.9214*intensity - 81.673;//Bot 2
             distance = 1.7369*intensity - 73.232;//Bot 3
            break;
        case 1:
            // distance =1.6369*intensity - 72.97;//Bot 2
            distance =  1.4055*intensity - 65.84;//Bot 3
            break;
        case 2:
            // distance = 1.5889*intensity - 65.907;//Bot 2
            distance = 1.5968*intensity - 79.193;//Bot 3
            break;
        case 3:
            // distance = 1.8732*intensity - 78.922;//Bot 2
            distance = 1.5068*intensity - 63.67;//Bot 3
            break;
        case 4:
            // distance = 2.1074*intensity - 86.835;//Bot 2
            distance = 2.0493*intensity - 95.69;//Bot 3
            break;

        case 5:
        //    distance = 1.9093*intensity - 80.002;//Bot 2
           distance = 1.3739*intensity - 61.794;//Bot 3
           break;
        case 6:
        //    distance = 1.6892*intensity - 71.084;//Bot 2
           distance = 1.9931*intensity - 88.442;//Bot 3
           break;
        case 7:
            // distance = 1.7187*intensity - 73.411;//Bot 2
            distance = 1.5659*intensity - 64.019;//Bot 3
           break;
        case 8:
        //    distance = 1.7463*intensity - 76.2;//Bot 2
           distance = 2.1791*intensity - 98.689;//Bot 3
           break;
        case 9:
            // distance = 1.6595*intensity - 68.838;//Bot 2
            distance = 2.4349*intensity - 107.39;//Bot 3
            break;
        case 10:
            // distance = 1.7076*intensity - 71.065;//Bot 2
            distance = 2.2621*intensity - 99.907;//Bot 3
            break;        
        case 11:
            // distance = 1.626*intensity - 67.416;//Bot 2
            distance = 1.2459*intensity - 49.236;//Bot 3
            break;
    }
    return distance;
}


//returns the which sensor the ball is closest to
int IRSensor::getBallAngle(){
    int lowestSensor =100000;
    int sensor;
    for(int i=0; i<12;i++){
        int intensity = analogRead(IR_PINS[i]);
        int distance = findSensorDistance(i,intensity);
        if(distance < lowestSensor){
            lowestSensor = distance;
            sensor = i;
        }
    }
    return sensor;
}


//puts raw data into curve then takes median
void IRSensor::readCalibratedSensors() {
    int min;
    int minIndex;
    for(int i = 0; i < numberMedianValues; i++) {
        min = 1e8;
        minIndex = -1;
        for(int j = 0; j < 12; j++) {
            sensorValues[j] = analogRead(IR_PINS[j]);
            sDistances[j].add(findSensorDistance(j, sensorValues[j]));
            if(sensorValues[j] < min) {
                minIndex = j;
                min = sensorValues[j];
            }
        }
        if(minIndex != -1) lowestPin[i] = (minIndex);
    }
}
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

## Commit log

2024-07-01 Photos from shrouded IR sensor calibration
2024-07-01 Update and rename Heat Maps.MARKDOWN to Heat Maps.md
2024-07-01 Rename 2324-RoboCup-SensorData0613-3d-1.png to IR Sensor Hardware/2324-RoboCup-SensorData0613-3d-1.png
2024-07-01 Rename 2324-RoboCup-SensorData0613-3d-1.png to Sensor With Shroud.png
2024-07-01 Rename Sensor With Shroud.png to Sensor 1 With Shroud.png
2024-07-01 Rename 2324-RoboCup-SensorData0613-3d-10.png to IR Sensor Hardware /2324-RoboCup-SensorData0613-3d-10.png
2024-07-01 Rename 2324-RoboCup-SensorData0613-3d-11.png to IR Sensor Hardware/2324-RoboCup-SensorData0613-3d-11.png
2024-07-01 Rename 2324-RoboCup-SensorData0613-3d-12.png to IR Sensor Hardware/2324-RoboCup-SensorData0613-3d-12.png
2024-07-01 Rename 2324-RoboCup-SensorData0613-3d-3.png to IR Sensor Hardware/2324-RoboCup-SensorData0613-3d-3.png
2024-07-01 Rename 2324-RoboCup-SensorData0613-3d-2.png to IR Sensor Hardware/2324-RoboCup-SensorData0613-3d-2.png
2024-07-01 Rename 2324-RoboCup-SensorData0613-3d-4.png to IR Sensor Hardware/Sensor 4 With Shroud.png
2024-07-01 Rename 2324-RoboCup-SensorData0613-3d-5.png to IR Sensor Hardware/Sensor 5 With Shroud.png
2024-07-01 Rename 2324-RoboCup-SensorData0613-3d-6.png to IR Sensor Hardware/Sensor 6 With Shroud.png
2024-07-01 Rename 2324-RoboCup-SensorData0613-3d-7.png to IR Sensor Hardware/Sensor 7 With Shroud.png
2024-07-01 Rename 2324-RoboCup-SensorData0613-3d-8.png to IR Sensor Hardware/Sensor 8 With Shroud.png
2024-07-01 Rename 2324-RoboCup-SensorData0613-3d-9.png to IR Sensor Hardware/Sensor 9 With Shroud.png
2024-07-01 Rename 2324-RoboCup-SensorData0613-3d-10.png to Sensor 10 With Shroud.png
2024-07-01 Rename 2324-RoboCup-SensorData0613-3d-3.png to Sensor 3 With Shroud.png
2024-07-01 Rename 2324-RoboCup-SensorData0613-3d-2.png to Sensor 2 With Shroud.png
2024-07-01 Rename 2324-RoboCup-SensorData0613-3d-12.png to Sensor 12 With Shroud.png
2024-07-01 Rename 2324-RoboCup-SensorData0613-3d-11.png to Sensor 11 With Shroud.png
2024-07-01 Update Heat Maps.md
    Added full description of data collection methods
2024-07-01 Rename IR Sensor Hardware/Heat Maps.md to IR Sensor Hardware/Heat Maps/Heat Maps.md
2024-07-01 Rename IR Sensor Hardware/Sensor 1 With Shroud.png to IR Sensor Hardware/Heat Maps/Sensor 1 With Shroud.png
2024-07-01 Rename IR Sensor Hardware/Sensor 10 With Shroud.png to IR Sensor Hardware/Heat Maps/Sensor 10 With Shroud.png
2024-07-01 Rename IR Sensor Hardware/Sensor 11 With Shroud.png to IR Sensor Hardware/Heat Maps/Sensor 11 With Shroud.png
2024-07-01 Rename IR Sensor Hardware/Sensor 12 With Shroud.png to IR Sensor Hardware/Heat Maps/Sensor 12 With Shroud.png
2024-07-01 Rename IR Sensor Hardware/Sensor 2 With Shroud.png to IR Sensor Hardware/Heat Maps/Sensor 2 With Shroud.png
2024-07-01 Rename IR Sensor Hardware/Sensor 3 With Shroud.png to IR Sensor Hardware/Heat Maps/Sensor 3 With Shroud.png
2024-07-01 Rename IR Sensor Hardware/Sensor 7 With Shroud.png to IR Sensor Hardware/Heat Maps/Sensor 7 With Shroud.png
2024-07-01 Rename IR Sensor Hardware/Sensor 4 With Shroud.png to IR Sensor Hardware/Heat Maps/Sensor 4 With Shroud.png
2024-07-01 Rename IR Sensor Hardware/Sensor 5 With Shroud.png to IR Sensor Hardware/Heat Maps/Sensor 5 With Shroud.png
2024-07-01 Rename IR Sensor Hardware/Sensor 6 With Shroud.png to IR Sensor Hardware/Heat Maps/Sensor 6 With Shroud.png
2024-07-01 Rename IR Sensor Hardware/Sensor 8 With Shroud.png to IR Sensor Hardware/Heat Maps/Sensor 8 With Shroud.png
2024-07-01 Rename IR Sensor Hardware/Sensor 9 With Shroud.png to IR Sensor Hardware/Heat Maps/Sensor 9 With Shroud.png
2024-07-01 Create IR Sensor.md
    Simple description of our robot
2024-07-01 Update IR Sensor.md
2024-07-01 Update Heat Maps.md
2024-07-09 camera code first upload
2024-07-10 Update and rename 4-21-24 Soccer Code/motorControlV2.cpp to 4-21-24 Soccer Code/notUsed/motorControlV2.cpp
2024-07-10 Update and rename 4-21-24 Soccer Code/motorControlV2.h to 4-21-24 Soccer Code/notUsed/motorControlV2.h
2024-07-10 Update and rename 4-21-24 Soccer Code/motorControlV3.cpp to 4-21-24 Soccer Code/Bottom Code/motorControlV3.cpp
2024-07-10 Update and rename 4-21-24 Soccer Code/motorControlV3.h to 4-21-24 Soccer Code/Bottom Code/motorControlV3.h
2024-07-10 Add current working bottom code
    Stays at initial angle using gyro, uses sine wave to move, and once the ball is at sensor 12 or 0 degrees, it moves forward at full speed
2024-07-10 Update and rename motorSine.ino to Bottom V3.cpp
2024-07-11 increase pwm frequency to 1khz
2024-07-11 Rename 2024 Soccer/Calibration Code/IRSensorTesting.cpp to Calibration Code/IRSensorTesting.cpp
2024-07-12 Update motorControlV3.cpp
    Changed pi to PI
2024-07-13 added color sensors to docs
2024-07-16 Update and rename main.cpp to FullPIDMethods.cpp
    File with all of the methods for PID. Still not done
2024-07-20 added pcb designs
    [24S IR PCB v12.brd, 24S Sensor Schematic v9.sch, MUXBreakout v46.brd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]

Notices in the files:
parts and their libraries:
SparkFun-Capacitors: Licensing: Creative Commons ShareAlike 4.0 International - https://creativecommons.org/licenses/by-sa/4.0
